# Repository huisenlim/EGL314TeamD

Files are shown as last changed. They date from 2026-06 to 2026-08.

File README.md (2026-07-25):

# EGL314 Experiental Ghost Hunting Game: POC
This repository contains the documentation of our experiential ghost hunting game utilising the **Ai-Thinker BU03-Kit** UWB modules (DW3000 + STM32F103) for live player tracking.  
This project has just passed the POC phase, and is documented as such.

## Table of Contents
1. [Project Overview](#1-Project-Overview)
2. [System Structure & Setup](#2-system-structure--setup)
* 2.1 [Basic structure](#21-basic-structure-of-system)
* 2.2 [Software & Hardware Setup](#22-software--hardware-setup)
* 2.3 [Tag configuration & Setup](#23-setup-of-tags--configuration)
3. [Game code for POC](#3-poc-game-code)  
* 3.1 [Tutorial](Tutorial.md)
4. [Running the game](#4-running-the-game)
5. [Repository Layout](#5-repository-layout)

# 1. Project Overview
This project aims to create an immersive and interactive experience through a 'ghost hunting game'.  
  
For this, the following hardware and software are used:

| Item | Qty | Remarks |
| --- | --- | --- |
| BU03-Kit UWB modules | 8 | 6 anchors and 2 tags. |
| Raspberry Pi 4 Model B | 2 | 1 rPi for running game code, and another for receiving UWB data through UART.  |
| Multiplay | - | For synchronised audio feedback |
| Physical button | 1 | Connected to game rPi so it can take in the button input. |
| Jumper wires | 2 | Soldered to the button and connected to rPi GPIO 27 |

All this is used to create a game where players use an item equipped with a rPi, button, and tag board to find and dispel ghosts through audio and visual cues.  

In order to win, the player must go dispel 3 ghosts within the 2 minute time limit by entering the vicinity of the ghost and pressing the button.   

Whenever a ghost is successfully dispelled, an additional 30 seconds is added, whereas if the button is pressed outside of the ghost's range, 5 seconds will be deducted.

# 2. System Structure & Setup

## 2.1 Basic structure of system
```mermaid
graph TD
A[BU03 Anchor 0]--UART-->B[Receiver rPi]
C[BU03 Anchor 1] --> A
D[BU03 Anchor 2] --> A
E[BU03 Anchor 3] --> A
F[BU03 Anchor 4] --> A
G[BU03 Anchor 5] --> A
B --OSC--> H[Game rPi]
H --OSC--> I[Multiplay]
```
## 2.2 Software & Hardware Setup
Before we start configuring the boards, we need to do some software setup for the Raspberry Pi by activating virtual environments and installing the required dependencies along with some hardware setup to connect the button to the Raspberry Pi.

Click [here](hardwareSoftwareSetup.md) for how.

## 2.3 Setup of tags & configuration
In this project, a single Ai-Thinker BU03-Kit module is configured as a tag, while six other modules are configured as fixed anchors placed around the game area. These are the fixed reference points used to calculate position.  

### Physical Setup
setupimg

The Raspberry Pi then reads live distance data from Anchor 00 over UART and sends it to our Game rPi which performs 2D multilateration, smooths the result with a Kalman filter, and renders live positions in a Tkinter and Matplotlib GUI.  
  
For this, each board has to be configured such that it understands its purpose and what it has to do.  

To learn more about how the BU03 modules work and how they are configured, click [here](TagSetupConfig.md)

# 3. POC game code
The programming of the game for POC includes the base game mechanic of dispelling ghosts with the tag and button, win/lose condition, synchronised SFX using Multiplay, and a [sequential tutorial](Tutorial.md).  

To view the in-depth guide on the GamePOC.py file, click [here](POCgameCode.md)

# 4. Running Tutorial and Game
To run the tutorial and game, first run uart.py on the receiver rPi using CLI inside the environment created during [software setup](https://github.com/huisenlim/EGL314TeamD/blob/main/hardwareSoftwareSetup.md#installing-virtual-environment):
```
python3 uart.py --host x.x.x.x --port 5005 --tags 1
```
Where x.x.x.x is the IP address of the game rPi.  
  
Then, simply run POCtutorial.py and GamePOC.py on the game rPi through CLI or VScode.

# 5. Repository Layout
```
.
├── README.md                  # this file
├── GamePOC.py                 # game file for POC
├── uart.py                    # for UART receiver pi
├── POCtutorial.py             # tutorial game file for POC
├── POCgameCode.md             # game file documentation
├── tutorial.md                # tutorial game file documentation
├── hardwareSoftwareSetup.md   # setup of hardware and software
├── TagSetupConfig.md          # setup and configuration of tag boards
└── ConfigFiles/               
    ├── bu03_detect.py         # UART connection confirmation
    ├── bu03_multi_config.py   # to config ID/role for each board
    ├── bu03_inspect.py        # reads back configuration
    ├── viewer_calibrate.py    # calibration for anchors
    └── check_uart.sh          # verification of UART mapping
```

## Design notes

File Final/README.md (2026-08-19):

# EGL314 Project Phantom MVP: The Final Showdown (Station 4)
An interactive and physical game of ghost hunting where player need to answer question, when they answer correctly, they are one step closer to restore the energy to kill the final ghost(bossman).

## Table of Content
1. [Project Overview](#1-Project-Overview)
2. [How The Game Works](#2-how-the-game-works)
3. [Game Setup](#3-game-setup)
*  3.1 [Equipment](#31-equipment-used)
4. [Software Setup](#4-software-setup)
*  4.1 [Audio](#41-audio-cues-setup)
*  4.2 [Visual](#42-lighting-cues-setup)
5. [Conditions For The Game](#5-conditions-for-the-game)
*  5.1 [Win Conditions](#51-win-condition)
*  5.2 [Lose Conditions](#52-lose-condition)
6. [Final Outcome](#6-final-outcome)

## 1. Project Overview
This station consists of players if they are paying attention to the trainers(host). Players have to answer 4 questions, after one correct answer the energy will be restored slowly until the last question is answered correctly, they will be able to defeat the final ghosts(bossman). The system tracks participants across defined arena zones and synchronizes stage lighting and multi-track audio to deliver a guided 4-question interactive game.

This is bossman:)
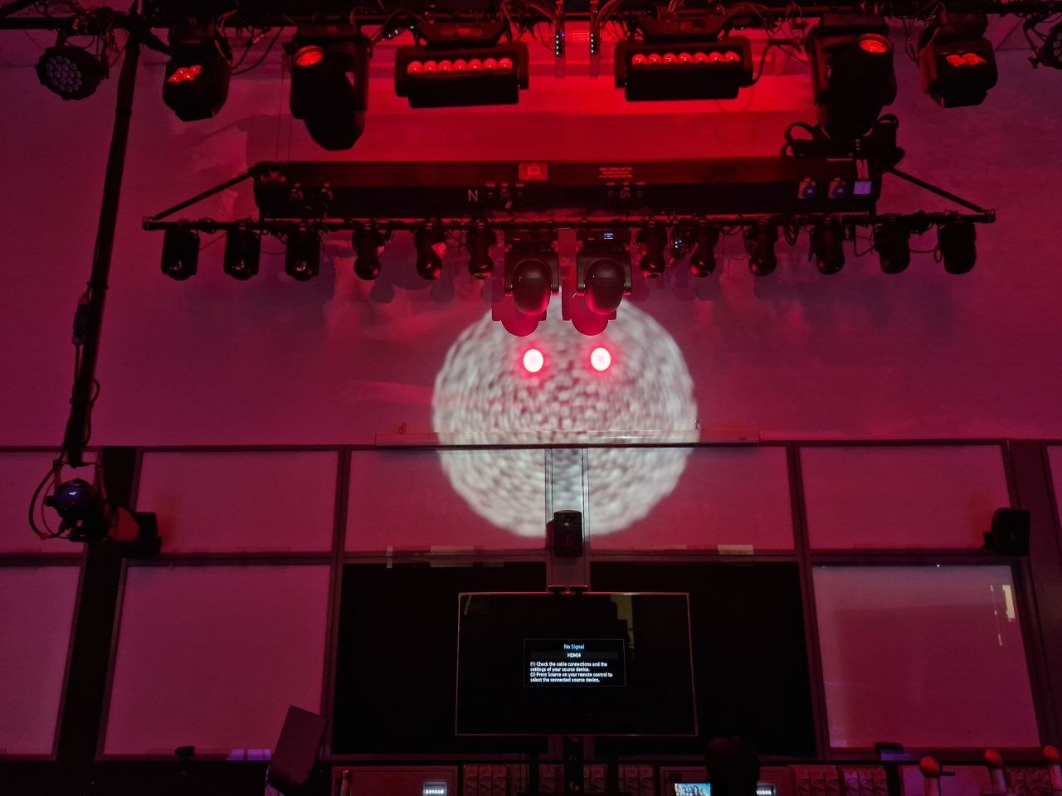
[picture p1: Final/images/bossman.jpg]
bossman


## 2. How The Game Works
The game is a synchronized spatial tracking and show automation system where trainees(players) have to answer the correct answer, trainers then will place a pillar in one of the option that the trainees(players) want and see if it is in the zone(correct option), if yes it will move on to the next question, if not players will have another try until they get correct. The Python engine processes real-time hardware positioning and coordinates stage lighting (grandMA3) and dynamic audio cues (REAPER) over Open Sound Control (OSC).

---

### **1. Zone Collision & Hit Detection**

* **Zone Radius Evaluation (`game_logic.py`)**:
Uses Euclidean distance to determine whether a smoothed tag coordinate $(px, py)$ falls within the active question's zone center $(zx, zy)$:

```python
def ptInGhost(point, ghost):
    if point is None: return False
    px, py = point; zx, zy = ghost["center"]; r = ghost["radius"] + GhostHitTol
    return ((px - zx)**2 + (py - zy)**2) <= (r * r)

```
To detect if tag is in zone.
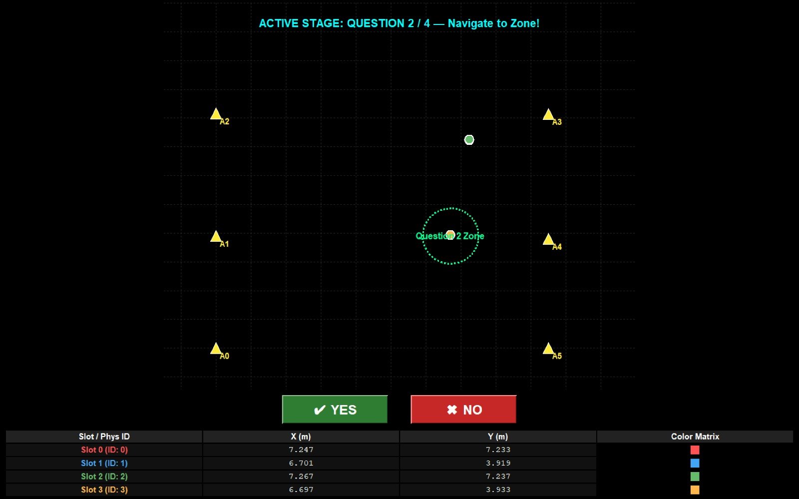
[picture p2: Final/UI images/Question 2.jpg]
tag in zone


---

### **2. Game Lifecycle & Show Automation**

* **Application Launch (`main.py`)**:
Unmutes all audio tracks in REAPER and sends grandMA3 to standby Cue 2 on Sequence 100:

```python
if hasattr(app, 'audio_controller'):
    app.audio_controller.unmute_all_tracks()

lighting.trigger_initial_startup_light()

```
When launch the code, there is a main staging light for when the trainers are first talking about how the game works.

* **Start Game Execution (`main.py`)**:
Turns off startup/tutorial lights, triggers Question 1 lights (Seq 93) with timed cues, and starts Track 6 Marker 20 intro audio:

```python
lighting.stop_startup_light()
lighting.stop_tutorial_lighting()

lighting.start_question_lighting(1)

if app and hasattr(app, 'audio_controller'):
    app.audio_controller.play_q1_intro()

```
When first run the code.
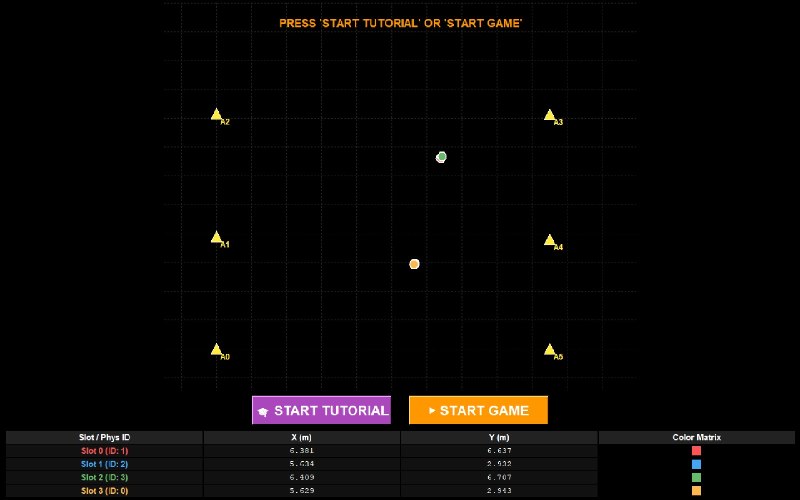
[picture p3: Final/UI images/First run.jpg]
first run


* **Timed Lighting Cues (`lighting.py`)**:
Schedules dynamic cue progression across sequences 93–96:

```python
seq_num = seq_info["question_seq"]
send_command(f"Go+ Sequence {seq_num}")

timings = QUESTION_CUE_TIMINGS.get(q_num, [])
for delay, cue in timings:
    timer = threading.Timer(delay, _trigger_cue, args=(cue, seq_num))
    active_cue_timers.append(timer)
    timer.start()

```

* **Intro-to-Ambient Audio Transition (`reaper.py`)**:
Plays the intro on Track 6 and automatically switches to Track 4 Marker 29 background audio once the intro duration finishes:

```python
self.play_marker(intro_marker_action)

self.marker_timer = threading.Timer(
    intro_duration_seconds, 
    lambda: self.play_marker(MARKER_29_TRK4)
)
self.marker_timer.start()

```
When pressed start game question 1 will be played audio and lighting will sync together when the bossman is saying the options. It will be the same until the last question is played.

This is Q1.
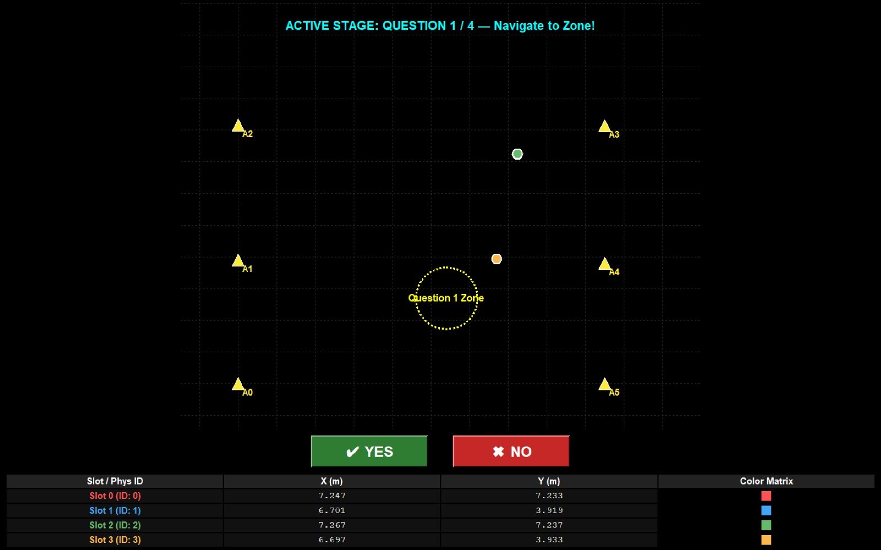
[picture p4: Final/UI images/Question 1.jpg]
Question1


This is Q2.
Question2

This is Q3.
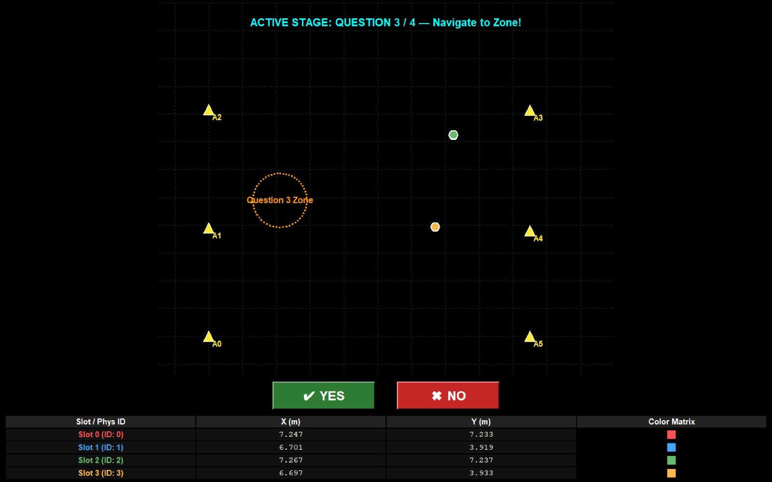
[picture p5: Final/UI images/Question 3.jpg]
Question3


This is Q4.
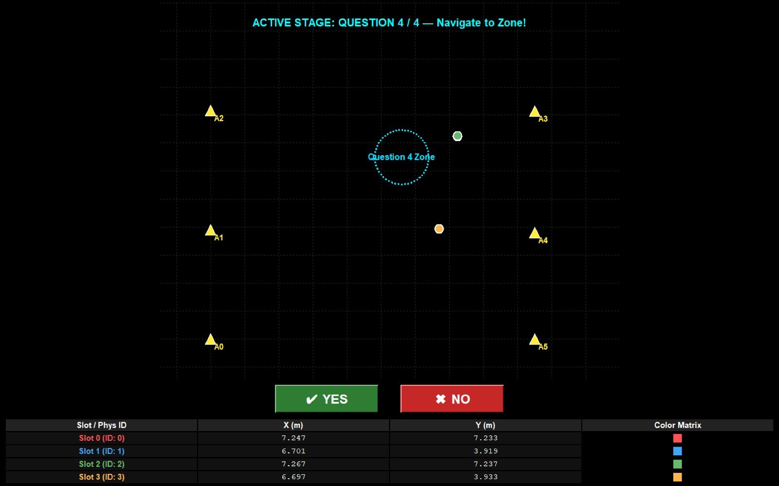
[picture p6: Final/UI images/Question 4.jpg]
Question4


---

### **3. Submissions: YES and NO Logic**

* **Standard YES (`main.py`)**:
Validates if a tag is inside the physical question zone before triggering success:

```python
for zi, ghost in enumerate(game_logic.Ghosts):
    if ghost.get("active", True) and ghost.get("question") == game_logic.CURRENT_QUESTION:
        if game_logic.ptInGhost(tag.filt_position, ghost):
            ghost["active"] = False
            hit_detected = True

if hit_detected:
    state.question_answered = True
    if app and hasattr(app, 'audio_controller') and game_logic.CURRENT_QUESTION < 4:
        app.audio_controller.play_yes_q1_to_q3()
    lighting.trigger_question_success_light(game_logic.CURRENT_QUESTION, audio_controller=audio_ctrl)

```
When tag is in the zone(correct answer), lightings will turn green and audio will play a "correct" sound when yes button is pressed.

* **NO Button & Auto-Retry Loop (`main.py` & `reaper.py`)**:
Triggers lighting Sequence 97 for 5s and plays Track 6 Marker 21 for 4s before automatically restarting the active question intro:

```python
# main.py
lighting.trigger_no_button_sequence()
if app and hasattr(app, 'audio_controller'):
    app.audio_controller.play_no_button(on_finish_callback=repeat_current_question_intro)

# reaper.py
def play_no_button(self, on_finish_callback=None):
    self._cancel_timer()
    self.play_marker(MARKER_21_TRK6)
    if on_finish_callback:
        self.marker_timer = threading.Timer(4.0, on_finish_callback)
        self.marker_timer.start()

```
When tag is not in the zone(correct answer), lightings will turn red and audio will play a "laughing" sound coming out of the bossman and audio will replay the question when no button is pressed.

This is the yes and no button.
button

---

### **4. Question 4 Finale Sequence (`lighting.py`)**

* **Multi-Stage Automated Finale**:
Fires Track 34 Marker 22 and Sequences 89 & 101, triggers Sequence 102 Cue 9 and Track 6 Marker 23 after 9 seconds, and executes grandMA3 `Go Macro 15` with Track 36 Marker 24 after 11 seconds:

```python
if q_num == 4:
    send_command("Go+ Sequence 101")
    if audio_controller:
        audio_controller.play_yes_q1_to_q3()
    threading.Timer(9.0, _q4_fade_seq102, args=(audio_controller,)).start()

def _q4_fade_seq102(audio_controller=None):
    send_command(f"Go+ Cue 9 Sequence {FINAL_DIMMER_SEQUENCE}")
    if audio_controller:
        audio_controller.play_seq102_fade_audio()
    threading.Timer(11.0, _q4_delayed_macro15_transition, args=(audio_controller,)).start()

def _q4_delayed_macro15_transition(audio_controller=None):
    send_command("Off Sequence 89")
    send_command(f"Go Macro {FINAL_MACRO}")
    if audio_controller:
        audio_controller.play_seq90_audio()

```
Once final question is correct audio will play a dialouge coming from bossman after that the bossman will fade away and victory lights will be cued.

---

### **5. End Game Cleanup (`main.py` & `lighting.py`)**

* **Safe System Teardown**:
Stops all active audio transport in REAPER and sends grandMA3 to Cue 9 on Sequence 102:

```python
# main.py
if app and hasattr(app, 'audio_controller'):
    app.audio_controller.stop_all_audio()

lighting.end_game_lighting_cleanup()

# lighting.py
def end_game_lighting_cleanup():
    cancel_active_cue_timers()
    send_command(f"Go+ Cue 9 Sequence {FINAL_DIMMER_SEQUENCE}")

```
Once end game button is pressed, it will stop all cues both lighting and audio.

This is the end game button.
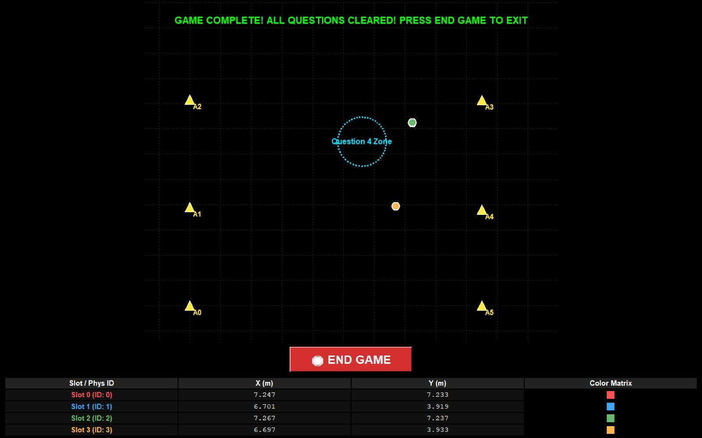
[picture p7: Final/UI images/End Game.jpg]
End Game


---

## 3. Game Setup
### 3.1 Equipment used
| Item | Qty | Remarks |
| --- | --- | --- |
| BU03-Kit UWB modules | 10 | 6 anchors and 4 tags. |
| Laptop | 1 | for running game code, and another for receiving UWB data through UART.  |

## 4. Software Setup
For software both audio and lighting need to sync with each other to obtain the perfect game.
### 4.1 Audio Cues Setup
#### 🛠️ 1. REAPER OSC Configuration

To allow Python to trigger audio markers over UDP:

1. Open REAPER.
2. Go to **Options** > **Preferences** (`Ctrl+P` / `Cmd+,`).
3. Under **Control/OSC/web**, click **Add**.
4. Configure:
   - **Control surface mode:** `OSC (Open Sound Control)`
   - **Pattern config:** `Default`
   - **Mode:** `Receive on UDP port`
   - **Listen port:** `8000`
5. Click **OK** and **Apply**.

---

#### 📌 2. REAPER Track & Marker Mapping

Question triggers route through **Track 3**, while game events route through **Tracks 33–36**:

| Track | Event / Scenario | Marker ID | Action |
| :--- | :--- | :---: | :--- |
| **Track 3** | Question 1 Audio | **20** | `Q1 Start / Cue` |
| **Track 3** | Question 2 Audio | **25** | `Q2 Start / Cue` |
| **Track 3** | Question 3 Audio | **26** | `Q3 Start / Cue` |
| **Track 3** | Question 4 Audio | **27** | `Q4 Start / Cue` |
| **Track 33** | Miss the Ghost | **21** | `Miss Sound Effect` |
| **Track 34** | Hit the Ghost | **22** | `Hit Sound Effect` |
| **Track 35** | Ghost Lose / Defeated | **23** | `Ghost Defeat Music` |
| **Track 36** | Victory Song | **24** | `Victory Fanfare` |

---

#### 💡 3. Audio & Lighting Synchronization Matrix

When an event triggers in Python, it dispatches OSC messages to both REAPER (`127.0.0.1:8000`) and grandMA3 (`192.168.254.252:8080`):

| Game Event | REAPER Track | REAPER Marker | grandMA3 Sequence |
| :--- | :---: | :---: | :--- |
| **Question 1** | Track 3 | Marker 20 | Sequence `93` |
| **Question 2** | Track 3 | Marker 25 | Sequence `94` |
| **Question 3** | Track 3 | Marker 26 | Sequence `95` |
| **Question 4** | Track 3 | Marker 27 | Sequence `96` |
| **Miss Ghost** | Track 33 | Marker 21 | Sequence `103` |
| **Hit Ghost** | Track 34 | Marker 22 | Sequence `104` |
| **Ghost Defeated** | Track 35 | Marker 23 | Sequence `105` |
| **Victory Song** | Track 36 | Marker 24 | Sequence `106` |

---
### 4.2 Lighting Cues Setup
The lighting module is responsible for sending Open Sound Control (OSC) commands directly to a grandMA3 console. It manages the visual atmosphere of the Interactive Question Arena by triggering specific light sequences, timed cues, and macros dynamically based on the active game state.

```python
# ───────── GMA3 NETWORK CONFIGURATION ─────────
GMA3_IP = "192.168.254.252"   # Replace with your grandMA3 console IP
GMA3_PORT = 8080             # Default grandMA3 inbound OSC port
GMA3_ADDR = "/gma3/cmd"
# ─────────────────────────────────────────────
```

```python
try:
    client = udp_client.SimpleUDPClient(GMA3_IP, GMA3_PORT)
    print(f"[LIGHTING] Connected to grandMA3 at {GMA3_IP}:{GMA3_PORT}")
except Exception as e:
    client = None
    print(f"[LIGHTING ERROR] Failed to initialize OSC client: {e}")
```

To execute these actions on the console, a helper function converts string commands into raw OSC messages:
```python
def send_command(cmd_string: str):
    """Sends a raw command string to the grandMA3 command line."""
    if client:
        try:
            client.send_message(GMA3_ADDR, cmd_string)
        except Exception as err:
            print(f"[LIGHTING ERROR] Network send failed: {err}")
```
### 4.3 Lighting Setup Checklist
Use this checklist to verify that all Open Sound Control (OSC) commands from the Python game server are successfully reaching the grandMA3 console and triggering the correct sequences.

## 1. Network & Initialization
- [ ] **Network Connection:** Verify the grandMA3 console is set to IP `192.168.254.252` and listening for OSC on UDP port `8080`.
- [ ] **Application Launch:** Run `python main.py`. 
  - *Expected Console Action:* Triggers `Go+ Cue 2 Sequence 100`.
  - *Visual Check:* Baseline environmental startup lighting is active.

## 2. UI & Pre-Game States
- [ ] **Tutorial Mode:** Click **START TUTORIAL**.
  - *Expected Console Action:* Triggers `Go+ Sequence 91`.
- [ ] **Game Start Initialization:** Click **START GAME**.
  - *Expected Console Action:* Sends `Off Sequence 100` and `Off Sequence 91`.
  - *Expected Console Action:* Immediately triggers `Go+ Sequence 93` (Question 1 Intro).

## 3. Question Intros & Timed Cues
- [ ] **Staggered Cues (Stage 1):** While Question 1 is active, do not press any buttons for 20 seconds.
  - *Expected Console Action:* Automatically triggers Cues 1, 2, 3, and 4 on Sequence `93` at the 6s, 10s, 14s, and 18s marks.

## 4. Game Action Responses
- [ ] **Lose Condition (NO Button):** Click **NO**.
  - *Expected Console Action:* Triggers `Go+ Sequence 97`.
  - *Expected Console Action:* Wait exactly 5 seconds; system should automatically send `Off Sequence 97`.
- [ ] **Win Condition (YES Button):** Physically enter the Question 1 zone and click **YES**.
  - *Expected Console Action:* Turns `Off Sequence 93`.
  - *Expected Console Action:* Triggers Success `Go+ Sequence 86`.
- [ ] **Stage Progression (CONTINUE Button):** Click **CONTINUE**.
  - *Expected Console Action:* Turns `Off Sequence 86`.
  - *Expected Console Action:* Triggers the next stage intro `Go+ Sequence 94`.

## 5. Final Boss Sequence (Question 4)
- [ ] **Boss Win Trigger:** Reach Question 4, enter the zone, and click **YES**.
  - *Expected Console Action:* Turns `Off Sequence 96`.
  - *Expected Console Action:* Triggers `Go+ Sequence 89` and `Go+ Sequence 101` simultaneously.
- [ ] **Boss Fade (9s Delay):** Wait 9 seconds after the boss win.
  - *Expected Console Action:* System automatically triggers `Go+ Cue 9 Sequence 102`.
- [ ] **Boss Conclusion (11s Delay):** Wait another 11 seconds (20s total).
  - *Expected Console Action:* Turns `Off Sequence 89`.
  - *Expected Console Action:* Executes `Go Macro 15`.

## 6. System Shutdown
- [ ] **End Game:** Click the **END GAME** button.
  - *Expected Console Action:* Pending timers are cancelled.
  - *Expected Console Action:* Triggers `Go+ Cue 9 Sequence 102` to bring the arena to its final resting state.

### 4.4 grandMA3 OSC Configuration Guide
To allow the Python game server to communicate with the grandMA3 console, you must configure the console to receive incoming Open Sound Control (OSC) network commands. 

### 1. Network Session Verification
Before configuring OSC, ensure your console or onPC software is active within a network session.
*   Navigate to the **Network** menu.
*   Verify that your station is actively in a session (indicated by the green highlight in the station list).

OSC LIGHT NETWORK SESSION

### 2. OSC In & Out Configuration
The core communication settings are established in the OSC Input/Output menu.

Navigate to the **In & Out** menu and select the **OSC** tab on the left sidebar.

Configure the global OSC settings at the top of the screen:
*   **Interface:** Select the network interface that matches your local network IP (e.g., `Wi-Fi (192.168.254.252)`).
*   **Enable Output:** Ensure this button is toggled ON (highlighted in yellow).
*   **Enable Input:** Ensure this button is toggled ON (highlighted in yellow) to allow the console to listen for commands.

### 3. OSC Data Setup
Create a new OSC Data row (e.g., `OSCData 1`) in the main window and apply the following specific configuration parameters:

*   **Destination IP:** `192.168.254.252`
*   **Mode:** `UDP`
*   **Port:** `8080` (This must match the `GMA3_PORT` defined in your Python script)
*   **Prefix:** `gma3` (This acts as the root address block for incoming commands)

Ensure the following command toggles are enabled for this data row:
*   **Receive:** `Yes`
*   **Send:** `Yes`
*   **Receive Command:** `Yes` (Crucial for allowing remote execution of macros and sequences)
*   **Send Command:** `Yes`

OSC LIGHT

## 5. Conditions For The Game
When playing a trivia question game, there is always a correct and wrong answer.

### 5.1 Win Condition
To win the game, players must answer all 4 question correctly in order to defeat the final ghost(bossman).
#### Audio Part

#### Lighting Part
Sequence & Cue Mappings
Specific grandMA3 sequences are mapped to global game events:
*   **Startup State:** Sequence `100` (automatically triggers Cue 2 upon application launch).
*   **Tutorial Mode:** Sequence `91`.
*   **Incorrect Action (NO Button):** Sequence `97` (plays for exactly 5 seconds before a background thread automatically turns it off).
*   **End Game / Final Dimmer:** Sequence `102` (specifically Cue 9).
The game dynamically triggers specific grandMA3 sequences and timed cues based on player actions and UI events.

System Startup
When the application first launches, it triggers a baseline environmental lighting state.
```python
def trigger_initial_startup_light():
    """Runs Cue 2 on Sequence 100 upon application launch."""
    print("[LIGHTING] App Launched: Triggering Cue 2 on Sequence 100...")
    send_command(f"Go+ Cue 2 Sequence {STARTUP_SEQUENCE}")
```

#### Question & Success Sequences
Each of the 4 progressive game questions utilizes a dedicated introductory sequence and a corresponding success sequence upon clearance:
*   **Question 1:** Intro Sequence `93` ➔ Success Sequence `86`.
*   **Question 2:** Intro Sequence `94` ➔ Success Sequence `87`.
*   **Question 3:** Intro Sequence `95` ➔ Success Sequence `88`.
*   **Question 4 (Boss Stage):** Intro Sequence `96` ➔ Success Sequence `89`.

When a player physically enters an active Question Zone and successfully clicks YES, the system turns off the introductory sequence and fires a success sequence. 
```python
def trigger_question_success_light(q_num: int, audio_controller=None):
    """
    Cancels pending intro cues, turns OFF question sequence (93-96), 
    and runs corresponding success sequence (86-89).
    """
    cancel_active_cue_timers()  # Stop any intro cues from firing late
    
    seq_info = QUESTION_SEQUENCES.get(q_num)
    if seq_info:
        send_command(f"Off Sequence {seq_info['question_seq']}")
        send_command(f"Go+ Sequence {seq_info['success_seq']}")
```

### 5.2 Lose Condition
Players will only lose when they get the answer wrong but they can try again until they get it right.
#### Audio Part

#### Lighting Part
## ❌ Lose Condition (Incorrect Action)

A lose or incorrect condition occurs when a player clicks the **NO** button on the game dashboard. This is used to indicate an incorrect answer or action, temporarily halting the current hunt.

When the **NO** button is clicked, the system triggers `trigger_no_button_sequence()`:
*   **Trigger:** The system sends a `Go+ Sequence 97` command to the grandMA3 console.
*   **Duration:** This sequence plays a specific error lighting state for exactly 5 seconds.
*   **Reset:** A background thread automatically sends an `Off Sequence 97` command after the 5 seconds have elapsed. Following this, the audio and lighting intros for the current question are automatically repeated so the player can try again.

```python
def trigger_no_button_sequence():
    """Plays Sequence 97 for 5 seconds when NO is pressed, then turns it off."""
    print("[LIGHTING] NO Button Pressed: Triggering Sequence 97 for 5 seconds...")
    send_command(f"Go+ Sequence {NO_BUTTON_SEQUENCE}")
    
    # Schedule automatic OFF after 5 seconds
    threading.Timer(5.0, _stop_no_button_sequence).start()

def _stop_no_button_sequence():
    """Helper timer callback to turn OFF Sequence 97."""
    print("[LIGHTING] 5s elapsed: Turning OFF Sequence 97...")
    send_command(f"Off Sequence {NO_BUTTON_SEQUENCE}")
```

### 5.3 Output of game

These images show the output of the lighting effect of the game
Question 1
Q1
Question 2
Q2
Question 3
Q3
Question 4

Q4

## 6. Final Outcome
After defeating the final ghost(bossman), victory is served and trainees would be able to obtain their license to become a trainer.
#### Audio Part

#### Lighting Part
## Core Logic & Functions

## `start_question_lighting(q_num)`
Clears any active lighting timers to prevent cue overlap, activates the target question's intro sequence, and schedules the staggered timed cues required for that specific question.

## `trigger_question_success_light(q_num, audio_controller)`
Executed when players successfully conquer a containment field. It cancels any pending intro cues, turns off the active question sequence, and immediately activates the corresponding success sequence. 

### The Boss Transition Logic (Question 4)
When Question 4 is cleared, the system executes a complex, threaded chain of audio-visual events to conclude the hunt:
1.  **Phase 1:** Sequence `101` fires, accompanied by Track 34 Marker 22 audio playback.
2.  **Phase 2 (9s Delay):** The system triggers Cue 9 on Sequence `102` (Final Dimmer) while simultaneously triggering the track fade-out audio marker.
3.  **Phase 3 (11s Delay):** Once the audio fade finishes, Sequence `89` is turned off, Macro `15` is executed, and the final concluding audio marker plays.

### 👑 Final Boss Win (Question 4)
Defeating the final ghost (Question 4) triggers a specialized, multi-phase grandMA3 lighting transition to signify the end of the game:
1.  **Initial Clear:** Turns OFF Sequence `96`, triggers Success Sequence `89`, and simultaneously fires Sequence `101`.
2.  **9-Second Delay:** The system waits 9 seconds before automatically triggering Cue 9 on Sequence `102` (Final Dimmer fade).
3.  **11-Second Delay:** After 11 more seconds, the system turns OFF Sequence `89` and executes Macro `15` to conclude the visual experience.

For the final boss stage (Question 4), a special delayed lighting and audio transition sequence is triggered using threading.
```python
    # --- Special Transition Logic for Question 4 / Sequence 89 ---
    if q_num == 4:
        print("[LIGHTING] Q4 Cleared: Seq 89 active! Playing Track 34 Marker 22...")
        send_command("Go+ Sequence 101")
        
        # Step 1: Play Track 34 Marker 22 when Sequence 89 starts
        if audio_controller:
            audio_controller.play_yes_q1_to_q3()

        # Step 2: Hold for 9s before triggering Cue 9 on Sequence 102
        threading.Timer(9.0, _q4_fade_seq102, args=(audio_controller,)).start()
```
### Cleanup Utilities
*   **`cancel_active_cue_timers()`:** A safety utility that iterates through `active_cue_timers` and stops them, ensuring overlapping button presses don't cause late-firing cues.
*   **`end_game_lighting_cleanup()`:** Safely shuts down pending timers and triggers Cue 9 on Sequence `102` to dim the physical arena when the game session fully terminates.

## 📁 Repository Layout

The project is divided into the main host server scripts (which run the game engine, UI, and OSC integrations) and a lightweight hardware script intended for the Raspberry Pi.

```text
📦 EGL314TeamD
├── 📜 README.md             # Main project documentation
├── 🖥️ Host Server (Laptop/PC)
│   ├── 📜 main.py           # Central execution script; initializes UI and servers
│   ├── 📜 display.py        # Tkinter game dashboard and real-time visualization
│   ├── 📜 game_logic.py     # Defines anchor coordinates, play bounds, and zone logic
│   ├── 📜 game_state.py     # Thread-safe data classes managing player positions
│   ├── 📜 network.py        # OSC handler that throttles and processes UWB packets
│   ├── 📜 trilateration.py  # 2D positioning math and Kalman filter for smoothing
│   ├── 📜 tutorial_ui.py    # Dedicated UI module for player onboarding
│   ├── 📜 lighting.py       # grandMA3 integration for dynamic lighting cues
│   └── 📜 reaper.py         # REAPER DAW integration for automated audio mixing
└── 🍓 Raspberry Pi (Hardware)
    └── 📜 pi_transmitter.py # Reads UART sensor data and GPIO button presses via OSC
```

### 8. System Architecture
```mermaid
graph TD
    %% 1. Top Level Hardware & Sensor Node
    A[AI Thinker UWB Kit] -->|UART| B[Laptop -> game.py]
    
    %% 2. Core Game Logic Node
    B -->|OSC| C[Laptop -> game.py]
    
    %% 3. Subsystem Split
    C -->|OSC| D[REAPER]
    C -->|OSC| E[GrandMA3]
    
    %% 4. Lighting Subsystem
    E -->|Wireless DMX| F[Lighting Fixtures]
    
    %% 5. Audio Subsystem Pipeline
    D -->|Dry digital audio| G[L-ISA Processor]
    H[L-ISA Controller] -->|Control data| G
    G -->|Rendered audio via Dante| I[Yamaha QL1]
    I -->|Dante| J[Yamaha Amplifier]
    J -->|Amplified analog audio| K[Yamaha Speakers]

    %% Styling & Customizations
    style A fill:#1f2937,stroke:#6b7280,stroke-width:1px,color:#fff
    style B fill:#1f2937,stroke:#6b7280,stroke-width:1px,color:#fff
    style C fill:#1f2937,stroke:#6b7280,stroke-width:1px,color:#fff
    style D fill:#1f2937,stroke:#6b7280,stroke-width:1px,color:#fff
    style E fill:#1f2937,stroke:#6b7280,stroke-width:1px,color:#fff
    style F fill:#1f2937,stroke:#6b7280,stroke-width:1px,color:#fff
    style G fill:#1f2937,stroke:#6b7280,stroke-width:1px,color:#fff
    style H fill:#1f2937,stroke:#6b7280,stroke-width:1px,color:#fff
    style I fill:#1f2937,stroke:#6b7280,stroke-width:1px,color:#fff
    style J fill:#1f2937,stroke:#6b7280,stroke-width:1px,color:#fff
    style K fill:#1f2937,stroke:#6b7280,stroke-width:1px,color:#fff

    linkStyle default stroke:#9ca3af,stroke-width:1px,color:#9ca3af
```

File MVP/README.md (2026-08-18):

# EGL314 Project Phantom MVP: The Final Showdown (Station 4)
An interactive and physical game of ghost hunting where player position determines real-time tracking with audio and visual cues to elimate the ghosts.

## Table of contents
1. [Project Overview](#1-Project-Overview)
2. [How The Game Works](#2-how-the-game-works)
3. [Game Setup](#3-game-setup)
*  3.1 [Real-Time Tracking Setup](#31-tag-and-anchor-setup)
*  3.2 [Button Setup](#32-button-setup)
*  3.3 [Gun Setup](#33-gun-setup)
4. [Software Setup](#4-software-setup)
*  4.1 [Audio](#41-audio-cues-setup)
*  4.2 [Visual](#42-lighting-cues-setup)
5. [Conditions For The Game](#5-conditions-for-the-game)
*  5.1 [Win Conditions](#51-win-condition)
*  5.2 [Lose Conditions](#52-lose-condition)
6. [Final Outcome](#6-final-outcome)
*  6.1 [Overview Setup](#61-setup-overview)
*  6.2 [Session Flow](#62-session-flow-start-to-finish)
*  6.3 [Outcome](#63-final-outcomes)
*  6.4 [Checklists](#64-setup-checklist)
*  6.5 [Gameplay In Action](#65-gameplay-in-action)
*  6.6 [Demo](#66-demo-video)

## 1. Project Overview
An interactive, physical ghost-hunting experience where real-world player position drives a live game. Players carry UWB (ultra-wideband) location tags; the system trilaterates their position in an arena, checks it against "ghost" containment zones, and reacts in real time with a live arena visualization, dynamic stage lighting (grandMA3), and spatial audio (REAPER + L-ISA). Dispelling a ghost means physically walking into its zone and pressing a handheld button at the right moment.

## 2. How The Game Works
Players will be in an arena space which is in 536 classroom to clear ghosts("zones") across progressive waves before the countdown timer stops.

#### Tutorial Phase
* The application launches into a standby state.
* Players complete interactive tutorial prompts to learn position-tracking and pin/button mechanics.

#### Wave Progression & Area Clearing
* Completing the tutorial initiates the master countdown timer and unmutes the venue audio system.
* Target zones ("Ghosts") render on the arena map corresponding to the active Wave (Waves 1 through 3).
* There are 3 ghosts each in wave 1 and 2 and in the final wave there is one final boss to hunt.
* Players must physically move their assigned tracking tags into active target circles to clear them.
* Listen to the audio cues and and see the visual cues which is the lightings to know where the ghosts are.
* Clearing all target zones in the current wave automatically advances the arena to the next Wave stage.

```python
def setup_wave_ghosts():
    names = ["Bob", "Stewart", "Tim", "Kevin", "Carl", "Dave", "Jerry"]
    colors = ["#ffff00", "#00ff95", "#ff9900", "#00e1ff", "#f088f0", "#ff007f", "#fc9090"]
    ZONE_RADIUS = 0.80 
    
    ghosts_list = [
        {"center": (2.5, 6.0), "radius": ZONE_RADIUS, "min_radius": 0.10, "color": colors[0], "label": names[0], "active": True, "wave": 1},
        {"center": (7.0, 6.0), "radius": ZONE_RADIUS, "min_radius": 0.10, "color": colors[1], "label": names[1], "active": True, "wave": 1},
        {"center": (4.75, 3.5), "radius": ZONE_RADIUS, "min_radius": 0.10, "color": colors[2], "label": names[2], "active": True, "wave": 1},
        {"center": (2.5, 2.5), "radius": ZONE_RADIUS, "min_radius": 0.10, "color": colors[3], "label": names[3], "active": True, "wave": 2},
        {"center": (7.0, 2.5), "radius": ZONE_RADIUS, "min_radius": 0.10, "color": colors[4], "label": names[4], "active": True, "wave": 2},
        {"center": (4.75, 6.0), "radius": ZONE_RADIUS, "min_radius": 0.10, "color": colors[5], "label": names[5], "active": True, "wave": 2},
    ]
    
    # Generate random static coordinates for Wave 3 (Jerry)
    while True:
        rand_x = random.uniform(1.0, 8.5)
        rand_y = random.uniform(1.0, 7.0)
        too_close = False
        for existing in ghosts_list:
            ex, ey = existing["center"]
            if (rand_x - ex)**2 + (rand_y - ey)**2 < (1.80 ** 2):
                too_close = True
                break
        if not too_close:
            break

    ghosts_list.append({
        "center": (rand_x, rand_y),
        "radius": ZONE_RADIUS, 
        "min_radius": 0.10, 
        "color": colors[6], 
        "label": names[6], 
        "active": True, 
        "wave": 3
    })
    return ghosts_list

Ghosts = setup_wave_ghosts()
```

#### Win / Lose Conditions
* **Victory:** All target zones across all waves are cleared before the countdown hits `0.0s`.
* **Defeat:** The timer reaches `0.0s` while active targets remain uncleared.
---
This is Wave 1.
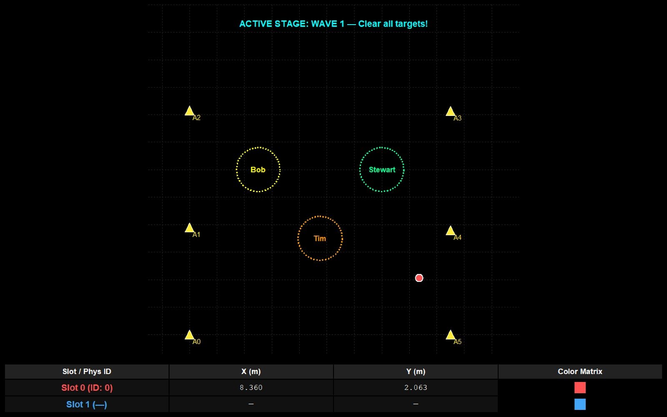
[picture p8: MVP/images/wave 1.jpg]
Wave 1


This is Wave 2.
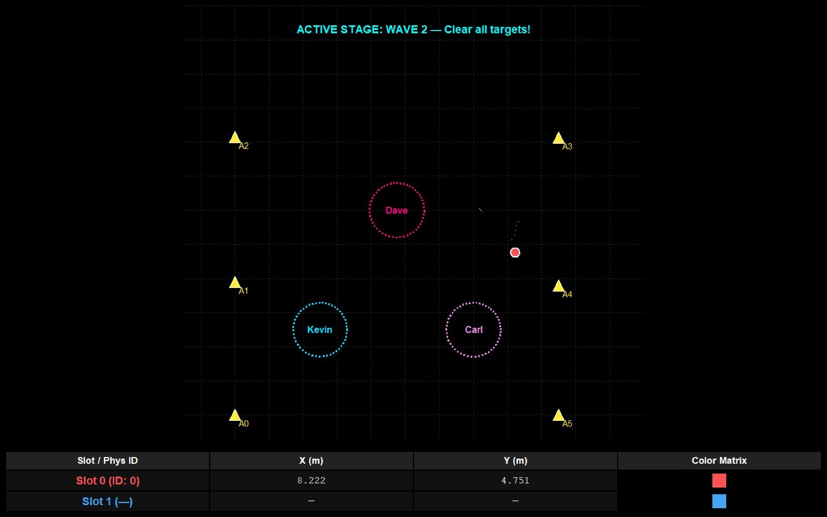
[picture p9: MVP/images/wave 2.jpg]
Wave 2


This is Wave 3 but coordinates will change everytime the code runs.
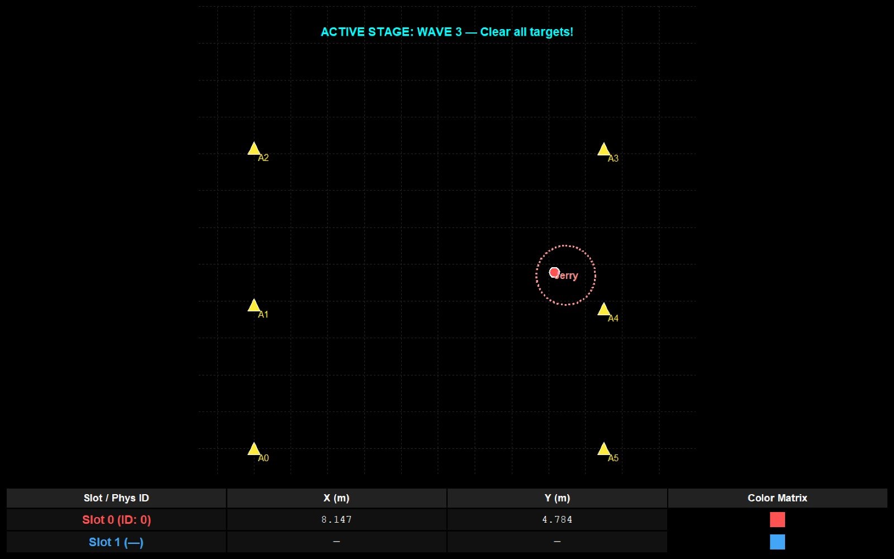
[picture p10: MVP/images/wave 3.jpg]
Wave 3


---
Next we will show you how the game is setup together with the software.

## 3. Game Setup
When setting up the game, we need some physical components to make the game work like tags and anchor, button, and lastly creating of the gun so it makes the game looks real and interesting.

### 3.1 Tag and Anchor Setup
The Ghost Game uses six fixed UWB anchors positioned around the play area to create a tracking zone. The anchors communicate with the UWB tag carried by the player, allowing the system to measure distances and calculate the player's real-time position within the game area.

The anchors act as fixed reference points, while the tag moves with the player. By using the distance measurements between the tag and multiple anchors, the system can determine the player's location and track their movement in relation to the virtual ghosts.

UWB Anchor Configuration

This is 1 of 6 anchors positioned around the play area for a tracking zone.
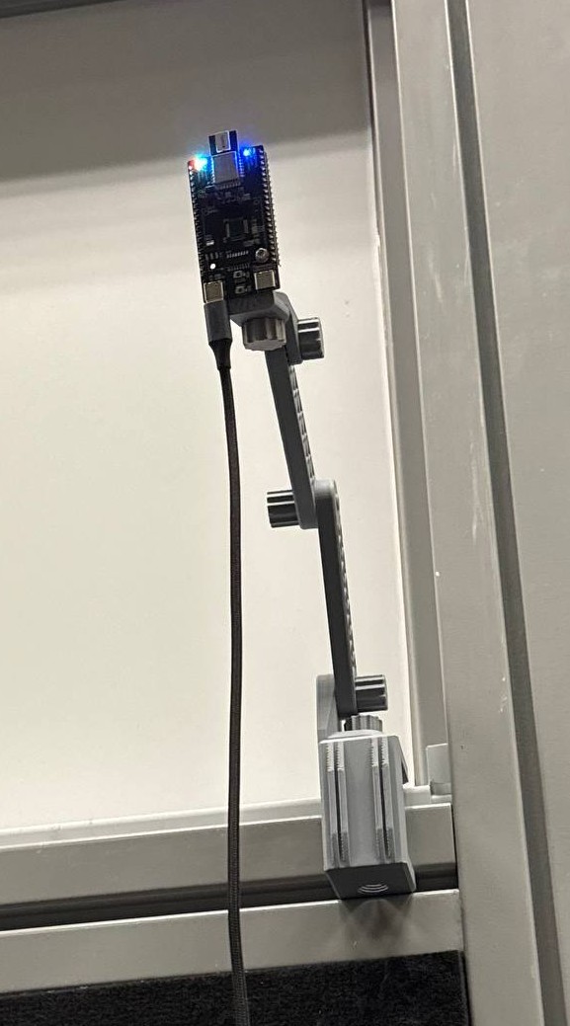
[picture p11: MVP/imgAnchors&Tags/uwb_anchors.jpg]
UWB Anchor Configuration


This is the top view of the tag used during MVP

The UWB tag was positioned at a higher level on the player to reduce the possibility of signal obstruction caused by the human body. Since the human body can interfere with or block the direct signal path between the UWB tag and the surrounding anchors, placing the tag higher provides a clearer line of sight to the anchors.

This helps improve the reliability and stability of the distance measurements as the player moves around the tracking area. The higher placement also reduces the chance of the tag being obstructed by the player's body, helping the UWB system maintain more consistent tracking performance.

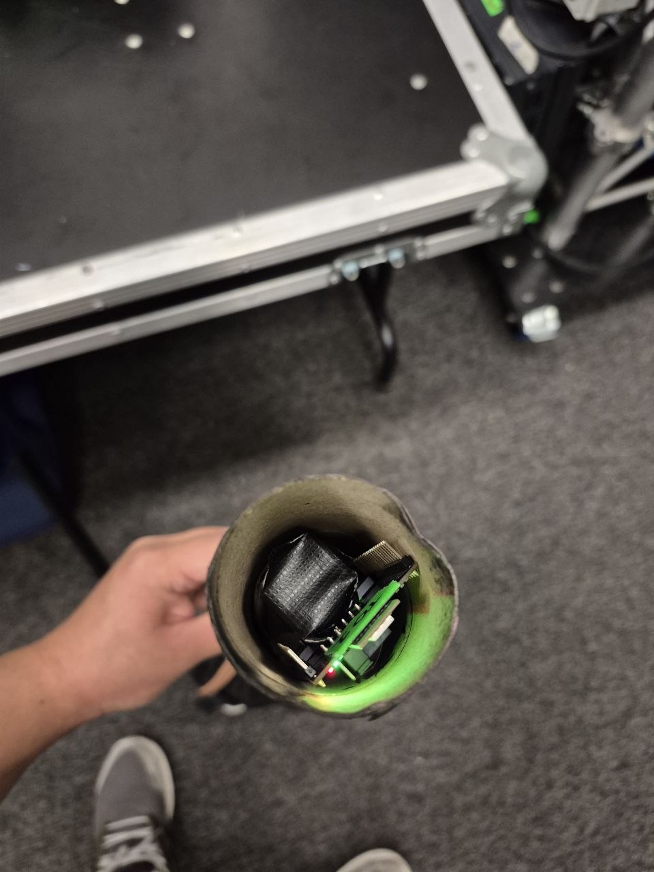
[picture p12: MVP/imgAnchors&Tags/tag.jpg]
UWB Anchor Configuration


The UWB tag was attached to the end of a rod, which was then placed inside a haversack worn by the player. This setup positioned the tag higher on the player's body, helping to reduce signal obstruction caused by the human body. By elevating the tag, a clearer line of sight was maintained between the tag and the surrounding UWB anchors, improving the reliability and consistency of the tracking system during gameplay.

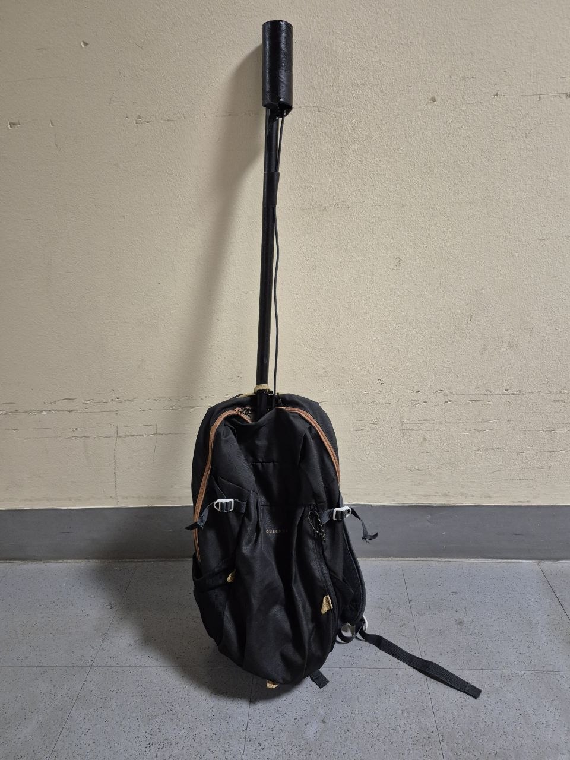
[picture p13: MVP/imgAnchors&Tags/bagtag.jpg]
UWB Anchor Configuration


These are the some 3d print used for the mount for the anchors.

These are the arms
[Click this link](3dPrintedFiles/longarms.3mf) to view the 3D print used for the UWB anchor.

These are the screws
[Click this link](3dPrintedFiles/screws.3mf) to view the 3D print used for the UWB anchor.

These is the clamp that holds the arms and screws together
[Click this link](3dPrintedFiles/clamp.3mf) to view the 3D print used for the UWB anchor.

This is the holder that i edited on UbuntuStudios so i can drill 2 small 2.5mm imperial screws through for a strengthened and stabalised anchor
 to view the 3D print used for the UWB anchor.

```python

ANCHORS = {
    0: (0.0, 0.0),
    1: (0.0, 3.9),
    2: (0.0, 8.16),
    3: (9.5, 8.14),
    4: (9.5, 3.8),
    5: (9.5, 0.0),
}

VIEW_BOUNDS = (-1.50, 12.0, -1.50, 12.0)
GhostHitTol = 0.25  
```

### 3.2 Button Setup
The dispel trigger is a single momentary push button wired to the Raspberry Pi's GPIO, read continuously in the background and forwarded to the game laptop as an event.

#### Wiring

| Pi Pin | Connection |
|---|---|
| GPIO 18 (BCM) | Button signal leg |
| GND | Button other leg |

The button is configured with an **internal pull-up**, so the pin reads HIGH when idle and LOW when pressed — `gpiozero` handles the inversion automatically.

```python
from gpiozero import Button

BUTTON_PIN = 18  # GPIO 18

button = Button(BUTTON_PIN, pull_up=True, bounce_time=0.2)
```

- `pull_up=True` — enables the internal pull-up resistor so no external resistor is needed
- `bounce_time=0.2` — 200ms software debounce, prevents a single physical press from registering as multiple rapid presses

#### Event handling

`gpiozero` exposes clean press/release callbacks, which are bound to a small helper that sends an OSC message to the game laptop:

```python
def send_button_event(is_pressed: bool):
    print(f"[PI] Button {'PRESSED' if is_pressed else 'RELEASED'} -> Sending to Laptop")
    client.send_message("/button", 1 if is_pressed else 0)

button.when_pressed  = lambda: send_button_event(True)
button.when_released = lambda: send_button_event(False)
```

Every press/release is sent as an OSC message to `/button` with a payload of `1` (pressed) or `0` (released). On the laptop side, `main.py` listens for this address and only acts on the **press** edge (not release) to avoid double-triggering:

```python
disp.map("/button", handle_remote_button)
```

For development without a Pi, the laptop also binds the **spacebar** to the same event handler, so the whole game can be tested without any hardware attached.

These photos shows the placement of the Raspberry Pi and button
photo_6280607123523702845_y
photo_6282823279403799343_y

---

### 3.3 Gun Setup

The "gun" is the handheld unit each player carries — it combines the **position tag** (UWB, reporting distance to anchors over UART) and the **dispel button** into one Raspberry Pi–driven transmitter. Its only job is to read hardware and forward everything to the game laptop over the network via OSC; it does no game logic itself. 

This is the link to all the components to 3D Print for the gun [3D Print Gun](./MVP/3dPrintedFiles/3D%20Print%20Gun/)

#### Components

- Raspberry Pi (or Pi Zero, depending on form factor)
- UWB tag module wired to the Pi's UART (`/dev/ttyS0` or `/dev/ttyUSB0`)
- Momentary push button on GPIO 18 (see [Button Setup](#1-button-setup))
- Wi-Fi connection to the same network as the game laptop

#### Configuration

Before deploying a gun, set these constants at the top of `pi_transmitter.py`:

```python
LAPTOP_IP = "192.168.1.XXX"  # Game laptop's local IP address
PORT = 5005                  # Must match --port used when launching main.py

SERIAL_PORT = "/dev/ttyS0"   # Or /dev/ttyUSB0 for a USB-to-UART adapter
BAUD_RATE = 115200
BUTTON_PIN = 18
```

> ⚠️ `LAPTOP_IP` is a placeholder — it must be updated to the actual laptop IP before each session, since it can change between networks/venues.

#### Runtime behavior

On startup, the gun opens a serial connection to the UWB tag and an OSC client pointed at the laptop:

```python
client = udp_client.SimpleUDPClient(LAPTOP_IP, PORT)
ser = serial.Serial(SERIAL_PORT, BAUD_RATE, timeout=0.1)
ser.flushInput()
```

It then loops continuously:

1. **Reads a line from UART** whenever data is available — the tag reports distances as a CSV string: `tag_id, d0, d1, d2, d3, d4, d5`
2. **Validates the packet** — needs at least 7 comma-separated values (1 tag ID + 6 anchor distances) to match what `network.py` expects on the laptop side
3. **Converts and forwards** the values as a `/distances` OSC message; malformed lines are silently skipped
4. **Button presses/releases** fire independently and asynchronously via the `gpiozero` callbacks described above — they aren't tied to the UART polling loop, so the gun stays responsive even if UART data is delayed

```python
if len(parts) >= 7:
    try:
        osc_payload = [float(val) for val in parts]
        client.send_message("/distances", osc_payload)
    except ValueError:
        pass  # Skip corrupted lines
```

A short `time.sleep(0.01)` keeps the polling loop from pegging the CPU while still comfortably outpacing the 20Hz throttle applied on the receiving end (`network.py`).

#### Multiple guns

Each gun just needs a unique `tag_id` embedded in its UART payload — the laptop auto-assigns each new physical tag ID to the next free UI "slot" the first time it's seen, so no per-gun code changes are required beyond flashing/wiring the tag itself.

---

## 4. Software Setup
Software setup is needed for audio cues and visual cues so that players will be able to hunt the ghosts by lightings and listening to the sound.

### 4.1 Audio Cues Setup

#### 🛠️ 1. REAPER OSC Configuration

To allow Python to trigger audio markers over UDP:

1. Open REAPER.
2. Go to **Options** > **Preferences** (`Ctrl+P` / `Cmd+,`).
3. Under **Control/OSC/web**, click **Add**.
4. Configure:
   - **Control surface mode:** `OSC (Open Sound Control)`
   - **Pattern config:** `Default`
   - **Mode:** `Receive on UDP port`
   - **Listen port:** `8000`
5. Click **OK** and **Apply**.

---

#### 📌 2. REAPER Track & Marker Mapping

Question triggers route through **Track 3**, while game events route through **Tracks 33–36**:

| Track | Event / Scenario | Marker ID | Action |
| :--- | :--- | :---: | :--- |
| **Track 3** | Question 1 Audio | **20** | `Q1 Start / Cue` |
| **Track 3** | Question 2 Audio | **25** | `Q2 Start / Cue` |
| **Track 3** | Question 3 Audio | **26** | `Q3 Start / Cue` |
| **Track 3** | Question 4 Audio | **27** | `Q4 Start / Cue` |
| **Track 33** | Miss the Ghost | **21** | `Miss Sound Effect` |
| **Track 34** | Hit the Ghost | **22** | `Hit Sound Effect` |
| **Track 35** | Ghost Lose / Defeated | **23** | `Ghost Defeat Music` |
| **Track 36** | Victory Song | **24** | `Victory Fanfare` |

---

#### 💡 3. Audio & Lighting Synchronization Matrix

When an event triggers in Python, it dispatches OSC messages to both REAPER (`127.0.0.1:8000`) and grandMA3 (`192.168.254.252:8080`):

| Game Event | REAPER Track | REAPER Marker | grandMA3 Sequence |
| :--- | :---: | :---: | :--- |
| **Question 1** | Track 3 | Marker 20 | Sequence `93` |
| **Question 2** | Track 3 | Marker 25 | Sequence `94` |
| **Question 3** | Track 3 | Marker 26 | Sequence `95` |
| **Question 4** | Track 3 | Marker 27 | Sequence `96` |
| **Miss Ghost** | Track 33 | Marker 21 | Sequence `103` |
| **Hit Ghost** | Track 34 | Marker 22 | Sequence `104` |
| **Ghost Defeated** | Track 35 | Marker 23 | Sequence `105` |
| **Victory Song** | Track 36 | Marker 24 | Sequence `106` |

---

### 4.2 Lighting Cues Setup
The lights is used when players are in the zone of the ghosts, lights will light up so that players will know when to press the button to dispel the ghosts.

It communicates with the grandMA3 console using OSC network commands over UDP.

```python
GMA3_IP = "192.168.254.252"   # Replace with your grandMA3 console/laptop IP address
GMA3_PORT = 8080             # Default grandMA3 inbound OSC port
GMA3_ADDR = "/gma3/cmd"
```
```python
try:
    client = udp_client.SimpleUDPClient(GMA3_IP, GMA3_PORT)
    print(f"[LIGHTING] Connected to grandMA3 at {GMA3_IP}:{GMA3_PORT}")
except Exception as e:
    client = None
    print(f"[LIGHTING ERROR] Failed to initialize OSC client: {e}")
```
---

#### Game State & Arena Lighting

When the game state transitions through different phases, it triggers main global lighting looks across the arena:

| Game Phase | Trigger / Action | What the Lighting Console Does | Command Used |
| :--- | :--- | :--- | :--- |
| **Tutorial Complete / Game Start** | Player finishes tutorial; active gameplay begins. | Turns on **Sequence 1, Cue 1.0** (Green Wash) to fill the room. | `Goto Cue 1.0 Sequence 1` |
| **Wave 3 (Final Boss)** | Players clear Waves 1 & 2 and reach the final stage. | Starts the **Final Boss sequence**. | `Go+ Sequence 35` |
| **Game Victory / Mission Complete** | Players clear all target zones before time runs out. | Turns off all ghost lights & final boss light, then fires the **Victory Look**. | `Off Sequence 35`<br>`Off [All Ghost Sequences]`<br>`Go+ Sequence 36` |

```python
def trigger_final_ghost_light():
    """Triggers the lighting sequence for the Wave 3 Final Boss."""
    send_command(f"Go+ Sequence {FINAL_GHOST_SEQUENCE}")

def trigger_game_finish_light():
    """
    Kills the final boss sequence and all mapped ghost sequences,
    then triggers the game completion sequence.
    """
    # 1. Kills the Final Boss sequence explicitly
    send_command(f"Off Sequence {FINAL_GHOST_SEQUENCE}")
    
    # 2. Ensures all standard ghost sequences are off
    for seq_id in GHOST_SEQUENCES.values():
        send_command(f"Off Sequence {seq_id}")
        
    # 3. Triggers the Victory / Game Over Sequence
    send_command(f"Go+ Sequence {GAME_OVER_SEQUENCE}")
```

---

#### Ghost Target Spotlights

When a player physically enters an active ghost's target zone inside the arena, that ghost's spotlight sequence turns **ON**. Stepping out or dispelling the ghost turns the sequence **OFF**.

```python
GHOST_SEQUENCES = {
    0: 31,  # Ghost 0 (Bob)
    1: 32,  # Ghost 1 (Stewart)
    2: 37,  # Ghost 2 (Tim)
    3: 34,  # Ghost 3 (Kevin)
    4: 29,  # Ghost 4 (Carl)
    5: 33,  # Ghost 5 (Dave)
}

def set_ghost_light(ghost_index: int, turn_on: bool):
    """Triggers or turns off the specific Sequence mapped to a ghost."""
    seq_id = GHOST_SEQUENCES.get(ghost_index)
    if seq_id is not None:
        if turn_on:
            send_command(f"Go+ Sequence {seq_id}")
        else:
            send_command(f"Off Sequence {seq_id}")

```
This is a Demo how it will look like for Wave 1 and 2.
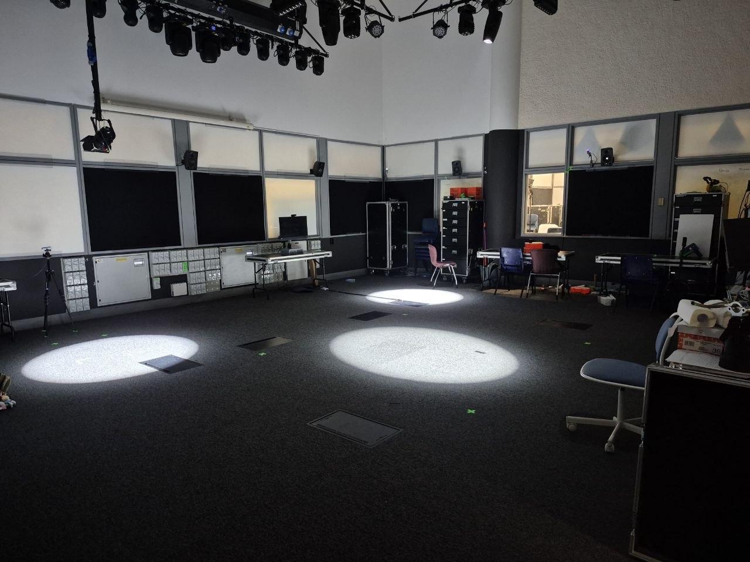
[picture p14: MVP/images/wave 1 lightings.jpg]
Wave 1 lightings

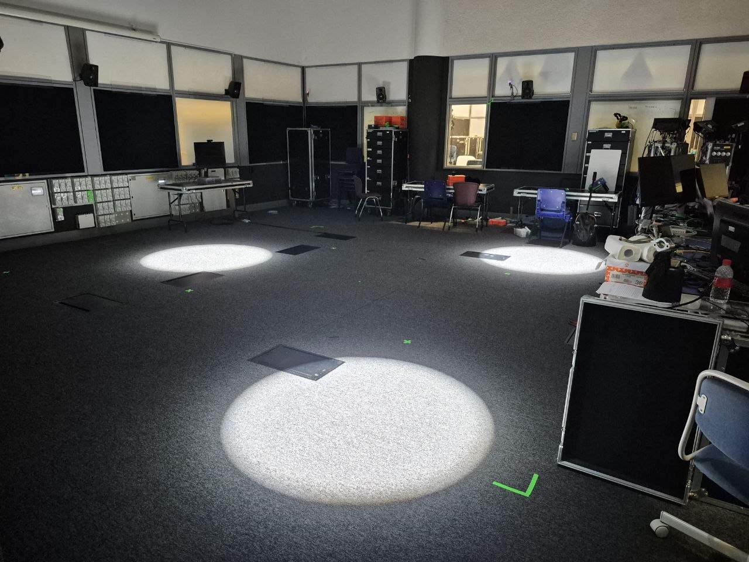
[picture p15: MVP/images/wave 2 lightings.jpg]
Wave 2 lightings


#### Ghost Sequence Mapping Table

| Target ID | Ghost Character | Target Zone Color | grandMA3 Sequence ID | Action on Walk-In | Action on Walk-Out / Dispel |
| :---: | :--- | :--- | :---: | :--- | :--- |
| **0** | **Bob** (Wave 1) | Yellow | `Sequence 31` | `Go+ Sequence 31` | `Off Sequence 31` |
| **1** | **Stewart** (Wave 1) | Bright Green | `Sequence 32` | `Go+ Sequence 32` | `Off Sequence 32` |
| **2** | **Tim** (Wave 1) | Orange | `Sequence 37` | `Go+ Sequence 37` | `Off Sequence 37` |
| **3** | **Kevin** (Wave 2) | Cyan / Light Blue | `Sequence 34` | `Go+ Sequence 34` | `Off Sequence 34` |
| **4** | **Carl** (Wave 2) | Pink / Purple | `Sequence 29` | `Go+ Sequence 29` | `Off Sequence 29` |
| **5** | **Dave** (Wave 2) | Hot Pink | `Sequence 33` | `Go+ Sequence 33` | `Off Sequence 33` |
| **6** | **Jerry** (Wave 3 / Boss) | Red / Pink | `Sequence 35` | `Go+ Sequence 35` | `Off Sequence 35` |

---

#### Quick Lighting Test Checklist

Use this checklist to troubleshoot or verify grandMA3 setup during arena configuration:

1. **Verify Network IP:** Ensure the lighting computer or console is set to static IP `192.168.254.252` and listening on Port `8080`.
2. **Check Command Path:** Confirm the console's OSC configuration accepts command-line OSC string payloads under `/gma3/cmd`.
3. **Manual Command Test:** Test target execution directly from the console command line:
   * **Turn On:** `Go+ Sequence 31` (Triggers Bob's spotlight)
   * **Turn Off:** `Off Sequence 31` (Clears Bob's spotlight)

## 5. Conditions For The Game
When playing a game, there is always a need for conditions so players can either win or lose the game.

There are 3 conditions to the game as well. Firstly, when tag is in the zone and button is pressed, the ghosts will be dispel. Secondly, when tag is not in zone but button is pressed, timer will add 5 seconds. Lastly, when tag is in zone but button is not pressed, nothing will happen.

```python
def handle_button_event(state, is_pressed):
        with state.lock:
            state.button_pressed = is_pressed
            
            # Only trigger hit detection on button PRESS down
            if is_pressed and not state.game_won and not state.game_lost and state.timer_active:
                hit_detected = False
                
                # STEP 1: Process tag hit checks for current wave ghosts
                for tag_id, tag in enumerate(state.tags):
                    if tag.filt_position is None:
                        continue
                    
                    for zi, ghost in enumerate(game_logic.Ghosts):
                        if ghost.get("active", True) and ghost.get("wave") == game_logic.CURRENT_WAVE:
                            if game_logic.ptInGhost(tag.filt_position, ghost):
                                print(f"\n🎯 DISPELLED: Tag {tag_id} hit Wave {game_logic.CURRENT_WAVE} Ghost [{ghost['label']}]!")
                                ghost["active"] = False
                                hit_detected = True
                                
                                # Turn OFF the individual light for this dispelled ghost
                                lighting.set_ghost_light(zi, turn_on=False)

                # STEP 2: Evaluate Wave Progression & Audio / Lighting Triggers
                if hit_detected:
                    state.time_left += 30.0
                    
                    # Trigger Ghost Kill sound in Reaper & L-ISA
                    if hasattr(app, 'audio_controller'):
                        app.audio_controller.trigger_alarm()
                    
                    # Check if all ghosts in the CURRENT wave are dispelled
                    wave_cleared = all(
                        not g.get("active", True) 
                        for g in game_logic.Ghosts 
                        if g.get("wave") == game_logic.CURRENT_WAVE
                    )
                    
                    if wave_cleared:
                        if game_logic.CURRENT_WAVE < 4:
                            game_logic.CURRENT_WAVE += 1
                            print(f"\n🌊 WAVE CLEARED! Transitioning to Wave {game_logic.CURRENT_WAVE}...")
                            
                            # Trigger Sequence when reaching Wave 3 (Final Boss)
                            if game_logic.CURRENT_WAVE == 3:
                                lighting.trigger_final_ghost_light()

                            root.after(0, app.force_instant_ui_refresh)
                        else:
                            state.game_won = True
                            state.timer_active = False 
                            print("\n🏆 !!! WIN CONDITION ACHIEVED !!! All arena grid sectors cleared! 🏆")
                            
                            # Kills final boss light and triggers victory sequence
                            lighting.trigger_game_finish_light()

                            root.after(0, app.force_instant_ui_refresh)
                    else:
                        root.after(0, app.force_instant_ui_refresh)
                else:
                    # Penalty for pressing button without hitting a ghost
                    state.time_left -= 5.0
```

### 5.1 Win Condition
To win the game, players must physically navigate the arena and **dispel all target ghosts across all 3 Waves** before the master countdown timer reaches zero.

---

#### Step-by-Step Victory Rules

1. **Active Wave Tracking:**
   * Players start at **Wave 1**.
   * Standing inside a ghost's target zone and pressing the tag button dispels that ghost.
   * Each time a ghost is dispelled, **+30 seconds** are added to the remaining timer as a reward.

```python
# Checks if the physical button press occurred inside an active ghost's radius
for zi, ghost in enumerate(game_logic.Ghosts):
    if ghost.get("active", True) and ghost.get("wave") == game_logic.CURRENT_WAVE:
        if game_logic.ptInGhost(tag.filt_position, ghost):
            ghost["active"] = False
            hit_detected = True
            lighting.set_ghost_light(zi, turn_on=False)

if hit_detected:
    state.time_left += 30.0  # +30s Reward
```
2. **Wave Progression:**
   * Once all ghosts in the active wave are cleared, the system automatically advances to the next wave:
     * **Wave 1 Cleared:** Progresses to Wave 2.
     * **Wave 2 Cleared:** Progresses to Wave 3 (Final Boss Stage).

```python
# Check if all ghosts in the current wave are inactive
wave_cleared = all(
    not g.get("active", True) 
    for g in game_logic.Ghosts 
    if g.get("wave") == game_logic.CURRENT_WAVE
)

if wave_cleared:
    if game_logic.CURRENT_WAVE < 4:
        game_logic.CURRENT_WAVE += 1
        if game_logic.CURRENT_WAVE == 3:
            lighting.trigger_final_ghost_light()  # Triggers Wave 3 Boss Light
```

3. **Final Victory Trigger:**
   * Clearing the final ghost in **Wave 3** immediately triggers the **WIN CONDITION**.

```python
# Triggered when Wave 3 is cleared
else:
    state.game_won = True
    state.timer_active = False 
    lighting.trigger_game_finish_light()
```

---

#### Hardware & System Victory Actions

The moment the final ghost is dispelled, `game_state.py` automatically executes the following actions across all connected hardware systems:

| Hardware System | System Action | What Happens in the Arena |
| :--- | :--- | :--- |
| **Countdown Timer** | **Freezes / Stops** | The timer halts immediately to lock in the players' final completion time. |
| **Arena Display HUD** | **Victory Banner** | Screen updates to render: `!!! WIN CONDITION ACHIEVED !!! Area Cleared!` |
| **Stage Lighting (grandMA3)** | **Victory Look** | Extinguishes all active ghost/boss spotlights (`Off Sequence 35`) and fires the **Victory Celebration Sequence** (`Go+ Sequence 36`). |
| **Spatial Audio (REAPER / L-ISA)** | **Mute / Audio Cue** | Triggers the final dispel snapshot, halts proximity tracking audio, and safely mutes overall track output via OSC commands. |

---

#### Penalty Logic

> [!WARNING]
> **Incorrect Button Presses:** Pressing the tag button while **outside** an active ghost target zone results in an immediate **5-second time penalty** deducted from the master timer.

```python
if not hit_detected:
    # Deduct 5 seconds if button pressed outside any target zone
    state.time_left -= 5.0
```

### 5.2 Lose Condition

The game is lost if the countdown timer reaches zero before every ghost in all three waves has been dispelled.

#### Timer mechanics

The timer lives in shared game state and only starts counting once the tutorial is completed:

```python
self.time_left = 150.0       # 150-second countdown
self.timer_active = False    # Stays paused until tutorial is dismissed
```

Once active, `display.py`'s render loop decrements it every frame based on real elapsed time (not a fixed tick), so it stays accurate regardless of frame rate:

```python
if self.state.timer_active and not self.state.game_won and not self.state.game_lost:
    delta = now - self.state.last_time
    self.state.time_left -= delta
    self.state.last_time = now

    if self.state.time_left <= 0:
        self.state.time_left = 0
        self.state.game_lost = True
        self.state.timer_active = False
```

#### What affects the clock

| Action | Effect |
|---|---|
| Dispelling a ghost (button press inside a zone) | **+30 seconds** |
| Pressing the button outside any active zone | **−5 seconds** (penalty for a wasted/wrong press) |

This means the timer isn't purely a countdown — good play actively buys more time, so the lose condition is really "run out of misses and time before clearing all ghosts."

#### On lose

When `time_left` hits zero:

- `state.game_lost = True` and `state.timer_active = False` are set, freezing the game
- The arena canvas title updates immediately:
  ```python
  self.canvas.itemconfig(self.title_text, text="MISSION FAILED — OUT OF TIME!", fill="#ff0000")
  ```
- The same message/color is re-applied by `force_instant_ui_refresh()` if triggered from elsewhere, so the fail state is consistent no matter what path set it
- The timer HUD window turns red (`#ff5252`) once under 30 seconds remaining, giving players a visual warning before the loss actually happens:
  ```python
  timer_color = "#ff5252" if (self.state.time_left < 30.0 and self.state.timer_active) else "#00ffff"
  ```
- Once `game_lost` is `True`, `main.py`'s button handler stops processing hit detection entirely — further button presses have no effect on game state

## 6. Final Outcome

 📋 Final Setup & Outcome Summary — Ghost Hunting Game

A wrap-up summary of the complete game setup, how a session plays out end-to-end, and the two possible final outcomes.

---

### 6.1 Setup Overview

| Layer | Component | Status |
|---|---|---|
| **Positioning hardware** | 6× fixed UWB anchors + per-player UWB tags | Configured via `game_logic.ANCHORS` |
| **Player device ("gun")** | Raspberry Pi + UWB tag (UART) + push button (GPIO 18) | `pi_transmitter.py` |
| **Network transport** | OSC over UDP, Pi → Laptop | Port `5005` (`--port`) |
| **Position engine** | Trilateration + Kalman filter | `network.py`, `trilateration.py` |
| **Game engine** | Wave/ghost state, hit detection, timer | `game_logic.py`, `game_state.py`, `main.py` |
| **Spectator display** | Live arena map, tag table, timer HUD, tutorial | `display.py`, `tutorial_ui.py` |
| **Lighting** | grandMA3 via OSC | `lighting.py` |
| **Audio** | REAPER + L-ISA via OSC | `reaper.py` |

**End-to-end flow:** UWB tags measure distance → Pi reads UART + button, forwards via OSC → laptop trilaterates position → game logic checks position against active ghost zones → display updates live → button press attempts a dispel → lighting + audio react → timer and wave state update → repeat until win or loss.

---

### 6.2 Session Flow (Start to Finish)

1. **Launch** — `main.py` starts the OSC server, opens the arena display, and waits
2. **Tutorial** — players complete the 4-step onboarding panel; timer stays paused (`timer_active = False`) until this finishes
3. **Hunt begins** — timer starts at `150.0s`, green "wash" lighting cue fires
4. **Wave 1 → 2 → 3** — players track ghosts via proximity beeping, walk into zones, and press the button to dispel; each successful dispel is `+30s`, each wasted press is `−5s`
5. **Round ends** — either all 3 waves are cleared (**win**) or the timer hits `0` first (**loss**)

---

### 6.3 Final Outcomes

#### 🏆 Win
- Fires when the **last ghost of wave 3** is dispelled
- `game_won = True`, timer stops instantly at whatever time remains
- `lighting.trigger_game_finish_light()` clears all ghost/boss sequences and triggers the **Victory** cue on grandMA3
- Arena title switches to green: `"GAME OVER — AREA CLEARED! YOU WIN!"`

#### ☠️ Lose
- Fires when `time_left` reaches `0` before all waves are cleared
- `game_lost = True`, timer freezes at `0.0`
- Arena title switches to red: `"MISSION FAILED — OUT OF TIME!"`
- **No lighting or audio cue currently fires on loss** — this is the one asymmetry between the two outcomes

#### After either outcome
- Button presses stop affecting the game (`handle_button_event` checks `not game_won and not game_lost`)
- The arena title and timer HUD simply freeze on-screen showing final state — there is no dedicated results/summary screen
- No stats are persisted anywhere (no logging of waves cleared, hit/miss counts, or time remaining/overrun)
- Returning to a fresh round currently requires restarting the app — `game_won`, `game_lost`, `time_left`, and ghost `active` flags are not reset in-session

---

### 6.4 Setup Checklist

Use this to confirm a venue is ready before a session:

- [ ] All 6 anchor coordinates in `game_logic.ANCHORS` match the physical arena
- [ ] `VIEW_BOUNDS` in `game_logic.py` covers the full playable area
- [ ] Each gun's `LAPTOP_IP` in `pi_transmitter.py` points to the current laptop IP
- [ ] `--port` on the laptop matches `PORT` in every gun's config
- [ ] `GMA3_IP` / `GMA3_PORT` in `lighting.py` reachable, and `GHOST_SEQUENCES` / `FINAL_GHOST_SEQUENCE` / `GAME_OVER_SEQUENCE` match the grandMA3 show file
- [ ] `REAPER_IP` / `LISA_IP` in `reaper.py` reachable, and marker/action IDs match the current REAPER project
- [ ] Buttons debounced and tested on all guns (`bounce_time=0.2`)
- [ ] Tutorial content reviewed and up to date (`tutorial_ui.py`)
- [ ] `--tags` set to the correct number of players for the session

### 6.5 Gameplay in Action
This photo below shows the player should be positioned in gameplay holding the handheld gun (tag + button), with a mounted anchor visible behind them
PLAYER

---
### 6.6 Demo Video
This video recording below shows the screen recording of the game
[MVP RECORDING.zip](https://github.com/user-attachments/files/30385286/MVP.RECORDING.zip)

The recording below shows a screen capture of gameplay in action
https://drive.google.com/file/d/1WY7LVYyNPCTMdVvlaRalucw68OrxDq7S/view?usp=drive_link

### 7. Repository Structure
```
EGL314TeamD/
└── MVP/
    ├── 3dPrintedFiles/
    │   └── 3D Print Gun/
    ├── GhostGameSoundV1/
    ├── GhostGameSound/
    ├── GhostGame/
    ├── UWB&Reaper/
    ├── images/
    ├── imgAnchors&Tags/
    └── README.md
```

### 8. System Architecture
```mermaid
graph TD
    %% 1. Top Level Hardware & Sensor Node
    A[AI Thinker UWB Kit] -->|UART| B[Sensor Pi -> uart.py]
    
    %% 2. Core Game Logic Node
    B -->|OSC| C[Laptop -> game.py]
    
    %% 3. Subsystem Split
    C -->|OSC| D[REAPER]
    C -->|OSC| E[GrandMA3]
    
    %% 4. Lighting Subsystem
    E -->|Wireless DMX| F[Lighting Fixtures]
    
    %% 5. Audio Subsystem Pipeline
    D -->|Dry digital audio| G[L-ISA Processor]
    H[L-ISA Controller] -->|Control data| G
    G -->|Rendered audio via Dante| I[Yamaha QL1]
    I -->|Dante| J[Yamaha Amplifier]
    J -->|Amplified analog audio| K[Yamaha Speakers]

    %% Styling & Customizations
    style A fill:#1f2937,stroke:#6b7280,stroke-width:1px,color:#fff
    style B fill:#1f2937,stroke:#6b7280,stroke-width:1px,color:#fff
    style C fill:#1f2937,stroke:#6b7280,stroke-width:1px,color:#fff
    style D fill:#1f2937,stroke:#6b7280,stroke-width:1px,color:#fff
    style E fill:#1f2937,stroke:#6b7280,stroke-width:1px,color:#fff
    style F fill:#1f2937,stroke:#6b7280,stroke-width:1px,color:#fff
    style G fill:#1f2937,stroke:#6b7280,stroke-width:1px,color:#fff
    style H fill:#1f2937,stroke:#6b7280,stroke-width:1px,color:#fff
    style I fill:#1f2937,stroke:#6b7280,stroke-width:1px,color:#fff
    style J fill:#1f2937,stroke:#6b7280,stroke-width:1px,color:#fff
    style K fill:#1f2937,stroke:#6b7280,stroke-width:1px,color:#fff

    linkStyle default stroke:#9ca3af,stroke-width:1px,color:#9ca3af
```

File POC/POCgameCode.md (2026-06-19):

# POC game code
This guide includes:
1. [Base of game](#1-base-game)
2. [Button input](#2-rapberry-pi-button-input)
3. [Ghost dispelling mechanic](#3-ghost-dispelling-mechanic)
4. [Winning condition](#4-win-condition)
5. [Lose condition](#5-lose-condition)
6. [Proximity beeping mechanic](#6-proximity-beeping-mechanic)  

Back to [README.md](README.md)

## 1. Base game  
The game consists of three ghosts.  
The information for each ghost is stored as a **dictionary** within a **list**, named 'Ghosts' as follows:
```python
Ghosts = [
    {
        "center": (0.25, 0.625),
        "radius": 0.15,
        "min_radius": 0.10,
        "color": "#ffff00",
        "label": "Bob",
        "active": True,
    },
    {
        "center": (0.75, 1.0),
        "radius": 0.15,
        "min_radius": 0.10,
        "color": "#fff700",
        "label": "Stewart",
        "active": True,
    },
    {
        "center": (0.75, 0.25),
        "radius": 0.15,
        "min_radius": 0.10,
        "color": "#fff700",
        "label": "Kevin",
        "active": True,
    },
]
```   

The function ptInGhost determines where the tag is from the ghost by using Pythagoras, and enter/exit events only fire once at the moment of crossing.  
```python
def ptInGhost(point, ghost):
    if point is None:
        return False
    px, py = point
    zx, zy = ghost["center"]
    r = ghost["radius"] + GhostHitTol
    dx = px - zx
    dy = py - zy
    return (dx * dx + dy * dy) <= (r * r)
```
Both of these allow the game to recognise where the ghosts and tags are in relation to one another and the anchors.  
This is then visualised in __init __, where mpatches.Circle patches added to the axes with dashed edges and ghost label text centred inside:
```python
self.ghost_patches = {}
        for zi, ghost in enumerate(Ghosts):
            cx, cy = ghost["center"]
            circle = mpatches.Circle((cx, cy), ghost["radius"], fill=False, linewidth=3, linestyle="-.", edgecolor=ghost["color"], alpha=0.9)
            self.ax_plot.add_patch(circle)
            txt = self.ax_plot.text(cx, cy, ghost["label"], color=ghost["color"], fontsize=11, ha="center", va="center", weight="bold")
            self.ghost_patches[zi] = (circle, txt)
```

## 2. Rapberry Pi button input 

### Pin Declaration & GPIO Setup

```python
BUTTON_PIN = 27
GPIO.setmode(GPIO.BCM)
GPIO.setup(BUTTON_PIN, GPIO.IN, pull_up_down=GPIO.PUD_UP)
```

This sets GPIO pin 27 as an input with an internal pull-up resistor, meaning the pin reads HIGH normally and goes LOW when the button is pressed.  

### Callback Function:

```python
def pin_edge_callback(channel):
    is_pressed = not GPIO.input(channel)
    with state.lock:
        state.button_pressed = is_pressed
        ...
```

This function runs automatically whenever the button is pressed or released. `not GPIO.input(channel)` flips the logic — since the pin is pull-up, a LOW signal (button pressed) becomes `True`.

### Edge Detection Registration

```python
GPIO.add_event_detect(BUTTON_PIN, GPIO.FALLING, callback=pin_edge_callback, bouncetime=200)
```

This is what actually "listens" for the button. `GPIO.FALLING` means it triggers on the HIGH→LOW transition (i.e. the moment the button is pressed down). The `bouncetime=200` is a 200ms debounce filter to prevent a single press from firing multiple times.

### Cleanup on Exit

```python
GPIO.cleanup()
```

At the very end in the `finally` block, this releases the GPIO pins safely when the program closes.

## 3. Ghost Dispelling Mechanic
When Player is in the vicinity of a ghost and presses the button, the ghost will be dispelled.  

When button is pressed
``` python
 def pin_edge_callback(channel):
        is_pressed = not GPIO.input(channel)
        with state.lock:
            state.button_pressed = is_pressed

            # --- FORCE IMMEDIATE DEACTIVATION ON PRESS ---
            if is_pressed:
                for tag_id, tag in enumerate(state.tags):
                    if tag.filt_position is None:
                        continue
```
And tag is in the zone where one of the ghosts is,
```python
for zi, ghost in enumerate(Ghosts):
                        if ghost.get("active", True):
                            # Check if this tag is inside this ghost right now
                            if ptInGhost(tag.filt_position, ghost):
                                print(f"\n🎯 HIT! Tag {tag_id} dispelled {ghost['label']}!")
                                ghost["active"] = False
```
the ghost will be removed by changing the ghost's active state to False.

This is where the loop will visually erase the ghosts from the screen during the user interface frame refresh loop.
```python
        self.root.after(40, self.update_loop)

for zi, ghost in enumerate(Ghosts):
            if not ghost.get("active", True) and zi in self.ghost_patches:
                circle, txt = self.ghost_patches[zi]
                try:
                    circle.remove()
                    txt.remove()
                except ValueError:
                    pass
                del self.ghost_patches[zi]
```

## 4. Win Condition
For the player to win, they must first carry the BU03 tag (a tracking device) and button.  
The player must both be in the vicinity of the ghost and press the button to dispel the ghost.  
Clear all three ghosts within the allocated time to win.

### Game Matrix
Firstly, the game matrix identifies if the tag is in the ghost zone.
```python
for zi, ghost in enumerate(Ghosts):
                    if ghost.get("active", True):
                        if ptInGhost(tag.filt_position, ghost):
                            current_ghosts.add(zi)

                tag.ghosts_inside = {zi for zi in current_ghosts if Ghosts[zi]["active"]}

                for zi, ghost in enumerate(Ghosts):
                    if ghost.get("active", True):
                        is_in_zone = ptInGhost(tag.filt_position, ghost)
```

Secondly, it sets the condition the player has to achieve to win the game.  

1. If button is pressed and tag is in the zone of the ghosts,
```python
 # Condition 1: Button is pressed AND tag is inside the ghost zone
                        if state.button_pressed and is_in_zone:
                            print(f"\n=== SUCCESS === Tag {tag_id} dispelled Ghost: {ghost['label']}!")
                            ghost["active"] = False
```
ghosts will be dispelled and zone will be removed.

2. Or, if button is pressed and tag is not in the zone of the ghosts,
```python
                        # Condition 2: Button is pressed AND tag is NOT inside the ghost zone
                        elif state.button_pressed and not is_in_zone:
                            pass # Ghost remains unaffected 
```
ghosts will remain.

3. Else if button is not pressed and tag is in the zone of the ghosts,
```python
# Condition 3: Button is NOT pressed AND tag is inside the ghost zone
                        elif not state.button_pressed and is_in_zone:
                            current_ghosts.add(zi) # Ghost remains, mark as occupying zone
```
ghosts will remain.

Lastly, after all ghosts is removed within the timeframe, player wins the game.
```python
                tag.ghosts_inside = {zi for zi in current_ghosts if Ghosts[zi]["active"]}
                
# Check for Win Condition (Are all ghosts turned off?)
                if all(not g.get("active", True) for g in Ghosts):
                    state.game_won = True
                    print("\n🏆 !!! CONGRATS!!! U WIN!!! ALL GHOSTS CLEARED!!! 🏆")
```

## 5. Lose Condition
The game starts with a 120-second countdown timer.  
Each time the player successfully dispels a ghost by pressing the correct button while inside the correct zone, 30 seconds are added to the remaining time.  
  
If the player attempts to dispel a ghost outside the designated zone, 5 seconds are deducted from the remaining time.  
The player will lose when the countdown timer reaches 0 seconds before all ghosts are dispelled.

### 120-Second Countdown from Game Start

```python
# ---------------------------------------------------------------------------
# Timer Configuration
# ---------------------------------------------------------------------------
TIMER_START_SECONDS  = 120   # starting countdown
TIMER_BONUS_CAPTURE  = 30    # seconds added on successful ghost capture
TIMER_PENALTY_MISS   = 5     # seconds deducted on wrong button press
```

```python
self.timer_end = time.time() + TIMER_START_SECONDS  # NEW: absolute deadline
```

**Where:** `SharedState.__init__()` inside the `SharedState` class.

The timer is not a simple counter. Instead, `timer_end` stores an **absolute future timestamp** — the current time plus 120 seconds. The remaining time is always computed as `timer_end - time.time()`, which means all bonuses and penalties just shift this deadline forward or backward.

### Additional 30 Seconds on Successful Ghost Dispel

This happens in **two places** — once in the OSC handler (continuous tracking), and once in the GPIO button callback (instant press detection).

### In the OSC handler (`make_osc_handler`):

```python
# Condition 1: Button is pressed AND tag is inside the ghost zone
if state.button_pressed and is_in_zone:
    print(f"\n=== SUCCESS === Tag {tag_id} dispelled Ghost: {ghost['label']}!")
    ghost["active"] = False
    # Bonus time for successful capture
    state.timer_end += TIMER_BONUS_CAPTURE
    print(f"[timer] +{TIMER_BONUS_CAPTURE}s bonus — new remaining: {state.timer_end - time.time():.1f}s")
```

### In the GPIO button callback (`pin_edge_callback`):

```python
if ptInGhost(tag.filt_position, ghost):
    print(f"\n🎯 HIT! Tag {tag_id} dispelled {ghost['label']}!")
    ghost["active"] = False
    hit_any_ghost = True
    # Bonus time for successful capture
    state.timer_end += TIMER_BONUS_CAPTURE
    print(f"[timer] +{TIMER_BONUS_CAPTURE}s bonus — new remaining: {state.timer_end - time.time():.1f}s")
```
When a successful hit is confirmed (button pressed + player is inside the ghost's zone), `TIMER_BONUS_CAPTURE` (30) is added directly to `timer_end`, pushing the deadline 30 seconds further into the future.

### -5 Seconds Deducted on a Missed Button Press

```python
# NEW: penalty if button pressed but no ghost was hit
if not hit_any_ghost:
    state.timer_end -= TIMER_PENALTY_MISS
    remaining = state.timer_end - time.time()
    print(f"\n❌ MISS! No ghost hit — -{TIMER_PENALTY_MISS}s penalty. Remaining: {remaining:.1f}s")
```

**Where:** Still inside `pin_edge_callback`, immediately after the ghost-hit loop.

If the button is pressed but `hit_any_ghost` remains `False` (the player wasn't inside any active ghost zone), `TIMER_PENALTY_MISS` (5) is **subtracted** from `timer_end`, bringing the deadline 5 seconds closer.

### Player Loses When Timer Reaches 0

```python
# --- TIMER EXPIRY CHECK (lose condition) ---
with self.state.lock:
    time_remaining = self.state.timer_end - now
    already_lost   = self.state.game_lost
    already_won    = self.state.game_won

if not already_won and not already_lost and time_remaining <= 0:
    with self.state.lock:
        self.state.game_lost = True
    print("\n💀 TIME'S UP — GAME OVER! You lose! 💀")
```

**Where:** `ViewerApp.update_loop()`, which runs every ~66ms via `root.after(66, self.update_loop)`.

Every UI refresh cycle, `time_remaining` is recalculated. The moment it hits zero or below (and the game hasn't already been won), `game_lost` is set to `True`. The display then updates accordingly:

```python
elif already_lost:
    self.timer_text.set_text("TIME'S UP!")
    self.timer_text.set_color("#ff0000")
```

```python
elif self.state.game_lost:
    self.ax_plot.set_title("GAME OVER — TIME'S UP! YOU LOSE!", color="#ff0000", fontsize=16, weight="bold")
```

---

### Summary Table

| Event | Code Constant | Effect on `timer_end` | Location |
|---|---|---|---|
| Game starts | `TIMER_START_SECONDS = 120` | Set to `now + 120` | `SharedState.__init__()` |
| Ghost dispelled (hit) | `TIMER_BONUS_CAPTURE = 30` | `+= 30` | `pin_edge_callback` / `make_osc_handler` |
| Button pressed, no ghost hit | `TIMER_PENALTY_MISS = 5` | `-= 5` | `pin_edge_callback` |
| Timer reaches 0 | — | `game_lost = True` | `ViewerApp.update_loop()` |

## 6. Proximity beeping mechanic
In order for players to decipher where ghosts are without a screen explicitly showing where the ghosts are, sound cues are added in order to hint at the location of the ghosts. 
   
4 different levels of beeping ranging in frequency will play depending on the distance of the player tag from the nearest ghost:

| Distance threshold | Cue |
| -- | -- |
| 0.0 | Cue 4 ( Fastest) |
| 0.25 | Cue 3 |
| 0.625 | Cue 2 |
| 1.0 | Cue 1 (Slowest)|
  
The faster the beeping, the closer the player is.   
Multiplay and Python OSC will be used to facilitate this mechanic in order for it to be synchronised with the game.

### Multiplay Address and Port

First, the Multiplay IP address and port are defined in the game's code:
```python
MULTIPLAY_IP   = "192.168.254.173"   # IP of the Multiplay machine
MULTIPLAY_PORT = 5005                # OSC UDP port Multiplay listens on
```
*Port must correspond to what is established in Multiplay OSC Control settings.  
Details written in [software setup](softwareSetup.md).

### Establishing Multiplay cue commands and corresponding radii

Next, the information for the sound cue and its threshold is defined here as a list:
```python
SOUND_CUE_THRESHOLDS = [
    (0.0,   "/cue/4/go"),   # right on the ghost  (hit tolerance)
    (0.25,  "/cue/3/go"),   # very close
    (0.625, "/cue/2/go"),   # medium range
    (1.0,   "/cue/1/go"),   # far away
]
```

This allows the code to be able to retrieve information for each distance from this list consistently without having to manually type it in every time.

The function 'nearest_ghost_distance' returns the minimum distance from the tag (point) to the centre of any active ghost:
```python
def nearest_ghost_distance(point):
    active = [g for g in Ghosts if g.get("active", True)]
    if not active:
        return float("inf")
    return min(dist_to_ghost(point, g) for g in active)
```
This is so that the code is able to discern the distance and thus which cue to play.  

```python
def cue_for_distance(distance):
    for threshold, address in SOUND_CUE_THRESHOLDS:
        if distance <= threshold:
            return address
    return None
```

cue_for_distance checks if the tag is within the cue thresholds stated above, then returns the Multiplay address written in SOUND_CUE_THRESHOLDS if it is, and None if it isn't.  

### MultiplayClient Class

Within the MultiplayClient class, there are 3 functions, '__init __', 'stop_all', and 'trigger'.
```python
class MultiplayClient:
    def __init__(self, ip: str, port: int):
        self._client = SimpleUDPClient(ip, port)
        print(f"[multiplay] OSC client initialised → {ip}:{port}")
```
__init __ initialises the Multiplay pythonOSC SimpleUDPClient for triggering Multiplay cues, creating a shared instance at startup and re-using it across all tags.  
  
Next, stop_all stops every currently active cue in Multiplay (/cue/all/stop).
```python
    def stop_all(self):
        try:
            self._client.send_message("/cue/all/stop", [])
            print("[multiplay] all cues stopped")
        except Exception as exc:
            print(f"[multiplay] stop_all failed: {exc}")
```
  
Finally, trigger stops all active cues, then immediately fires the requested cue.  
Stopping first guarantees no two proximity cues ever overlap, regardless of how Multiplay's own looping or auto-follow is configured.  

```python
    def trigger(self, address: str):
        try:
            self._client.send_message("/cue/all/stop", [])
            self._client.send_message(address, [])
            print(f"[multiplay] stopped all → cue sent: {address}")
        except Exception as exc:
            print(f"[multiplay] send failed ({address}): {exc}")
```

### Application in Game's Matrix

Within the game's main logic, these functions are applied like so:
```python
if multiplay_client and not state.game_won and not state.game_lost:
    dist = nearest_ghost_distance(tag.filt_position)
    new_cue = cue_for_distance(dist)
    if new_cue != tag.last_cue:
        if new_cue is not None:
            multiplay_client.trigger(new_cue)
        else:
            multiplay_client.stop_all()
        tag.last_cue = new_cue
```
It first checks if the game is still running by using an if statement to verify the game state is not won or lost, so that it will only send cues while the game is still running.  
stop_all() is called inside trigger() before the new cue fires, so overlaps are impossible.

---
Back to [README.md](README.md)

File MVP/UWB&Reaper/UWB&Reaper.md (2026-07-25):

## UWB Tracking and Immersive Audio System

### Anchor and Tag Configuration

The Ghost Game uses a UWB-based positioning system to track the player's movement within the game area.

Six UWB anchors were positioned around the designated play area. A laser distance measurer was used to measure and verify the distances between the anchors, ensuring that the physical positions of the anchors were accurately configured.

Accurate anchor placement is important because the system uses the measured distances between the anchors and the UWB tag to calculate the player's position within the tracking area.

After configuring the six anchors, a UWB tag was configured to track the player within the anchor area. The tag continuously communicates with the anchors, allowing the system to track the player's real-time location.

This tracking system forms the foundation of the Ghost Game. The player's calculated position is used to determine their distance from virtual ghosts placed within the game environment. Based on the player's proximity to a ghost, different audio, lighting, and gameplay responses can be triggered.

#### UWB Anchor Configuration Showcase

This is an Anchor, which is 1 of 6 that are mounted on a 3D print above head-height level to prevent any obstructions.

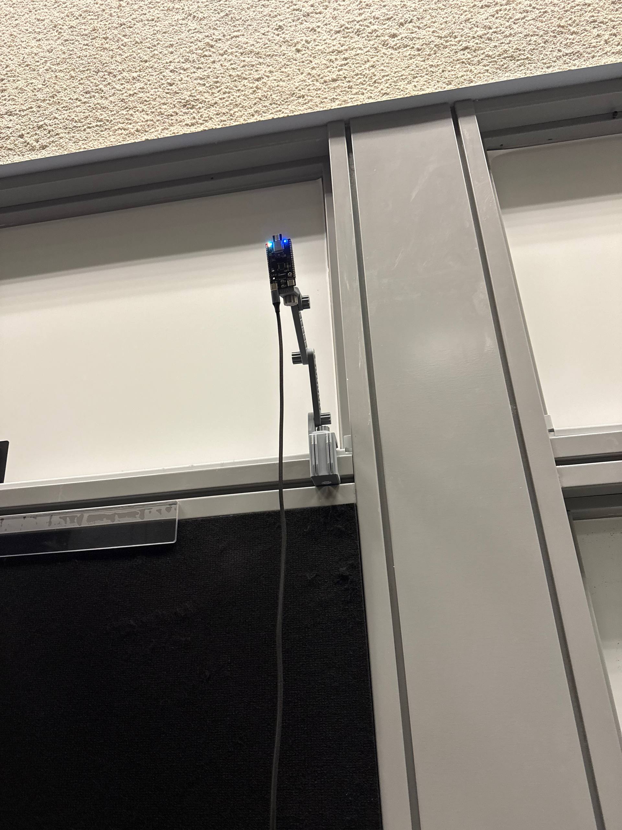
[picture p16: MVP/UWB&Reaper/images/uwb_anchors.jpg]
UWB Anchor Configuration


[Click this link](https://makerworld.com/en/models/2815216-heavy-duty-gravity-phone-mount-articulated-arm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) to go to the 3D print used for this documentation.

---

### REAPER Audio Integration

To create the audio system for the Ghost Game, a dedicated `reaper.py` module was developed as part of the `GhostGame` codebase.

The Python game system communicates with REAPER using OSC (Open Sound Control). The player's distance from a ghost is continuously monitored by the game, and different audio responses are triggered depending on the player's proximity.

The warning beep becomes faster as the player gets closer to a ghost, creating a more immersive and suspenseful gameplay experience.

The proximity system is divided into different stages:

- **Far Distance** – Slow warning beeps
- **Medium Distance** – Faster warning beeps
- **Close Distance** – Fast warning beeps
- **Ghost Interaction** – A separate audio event is triggered when the ghost is successfully eliminated

The `reaper.py` module sends OSC commands to REAPER to trigger the appropriate audio events. This allows the gameplay system to control the audio system in real time based on the player's position.

Using OSC communication, the Python game system and REAPER operate as separate systems while still communicating with each other over the network.

#### REAPER Track Configuration

The REAPER project was configured with multiple audio tracks to support the Ghost Game's proximity-based audio system. Different tracks were used for the various beeping stages and gameplay events.

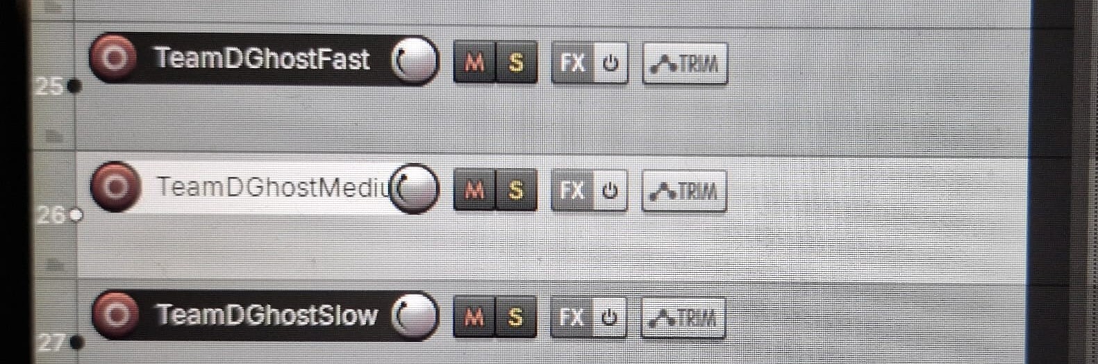
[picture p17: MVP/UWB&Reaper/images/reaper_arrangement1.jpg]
REAPER Audio Tracks


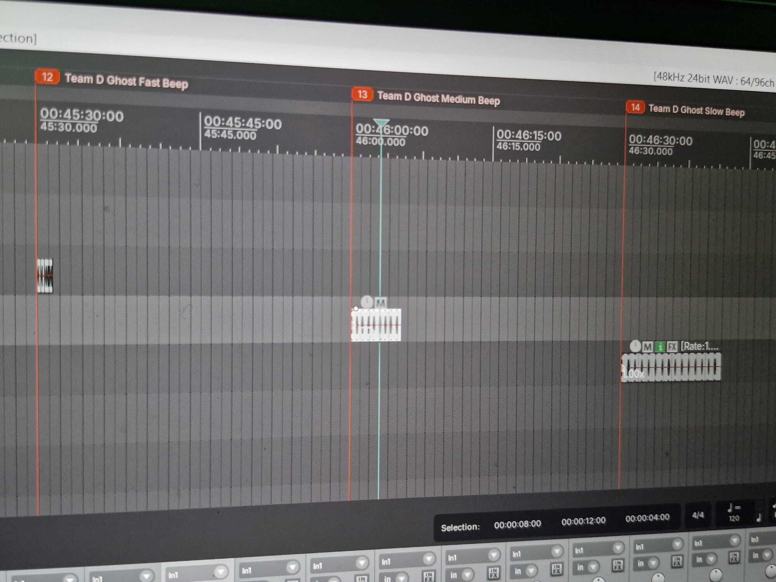
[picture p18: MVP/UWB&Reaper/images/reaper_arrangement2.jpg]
REAPER Audio Arrangement


---

### L-ISA Immersive Audio Integration

L-ISA was also integrated into the Ghost Game to provide a more immersive spatial audio experience.

The system uses 12 loudspeakers to create a larger and more immersive sound field for the player. This allows the audio system to provide greater spatial coverage compared to a conventional stereo setup.

The Python game system communicates with the L-ISA system using OSC commands. Different audio snapshots can be triggered based on the current gameplay state and the player's proximity to a ghost.

For example, different L-ISA audio states can be triggered for:

- Slow ghost proximity warning
- Medium ghost proximity warning
- Fast ghost proximity warning
- Ghost elimination

By combining UWB real-time tracking, REAPER audio playback, OSC communication, and L-ISA spatial audio, the Ghost Game creates an immersive audio experience where the sound system responds dynamically to the player's movement.

The 12-speaker setup helps create a more immersive environment by allowing audio to be distributed around the player. This enhances the feeling that ghosts are present within the surrounding environment and allows the audio system to become an important part of the gameplay experience.

#### L-ISA System Showcase

### L-ISA Controller Software

The L-ISA Controller software was used to create and manage the surround sound experience for the Ghost Game. It allows audio sources to be positioned and controlled within a spatial sound field, enabling sound to be distributed across the 12-speaker system.

Different audio configurations were saved as **snapshots**, with each snapshot representing a specific audio state or surround sound position. These snapshots could then be recalled during gameplay to change the audio experience based on the player's proximity to a ghost.

For example, different snapshots were used for slow, medium, and fast ghost proximity warnings, as well as specific gameplay events such as eliminating a ghost. This allowed the surround sound environment to respond dynamically to the player's movement and actions within the game.

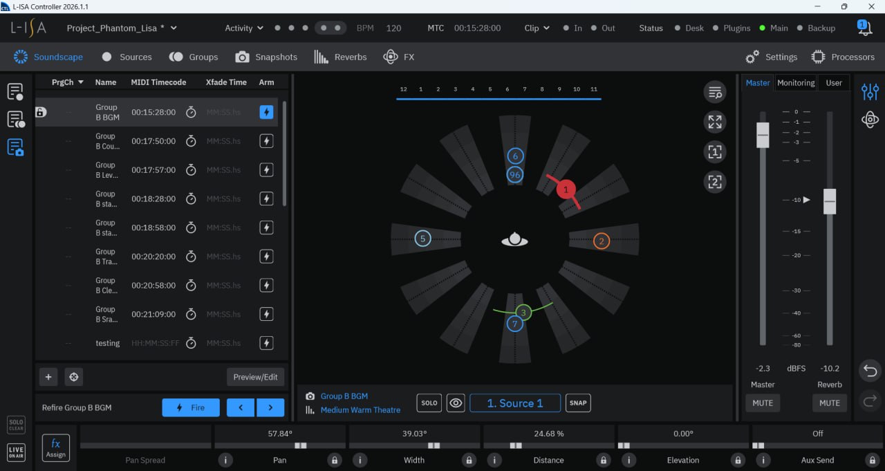
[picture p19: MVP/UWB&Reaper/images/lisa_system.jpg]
L-ISA Immersive Audio System


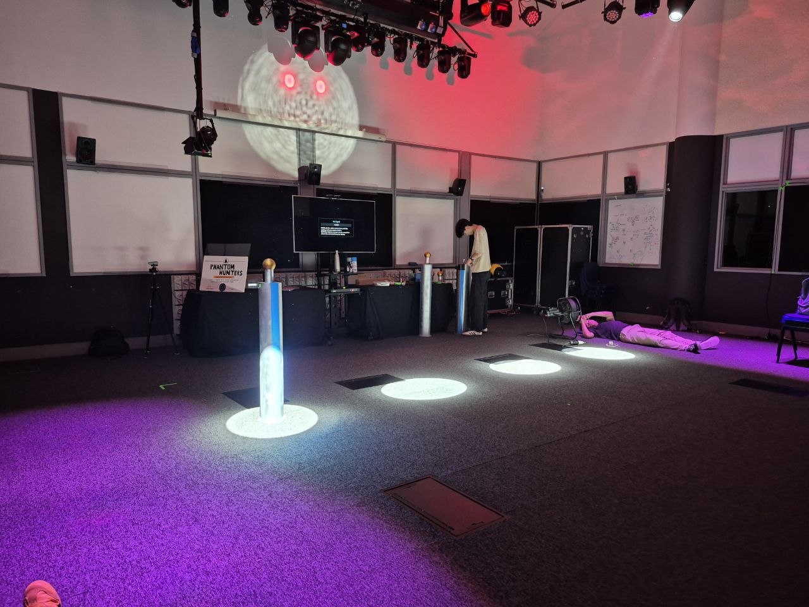
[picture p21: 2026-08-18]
Final/images/Q3.jpg

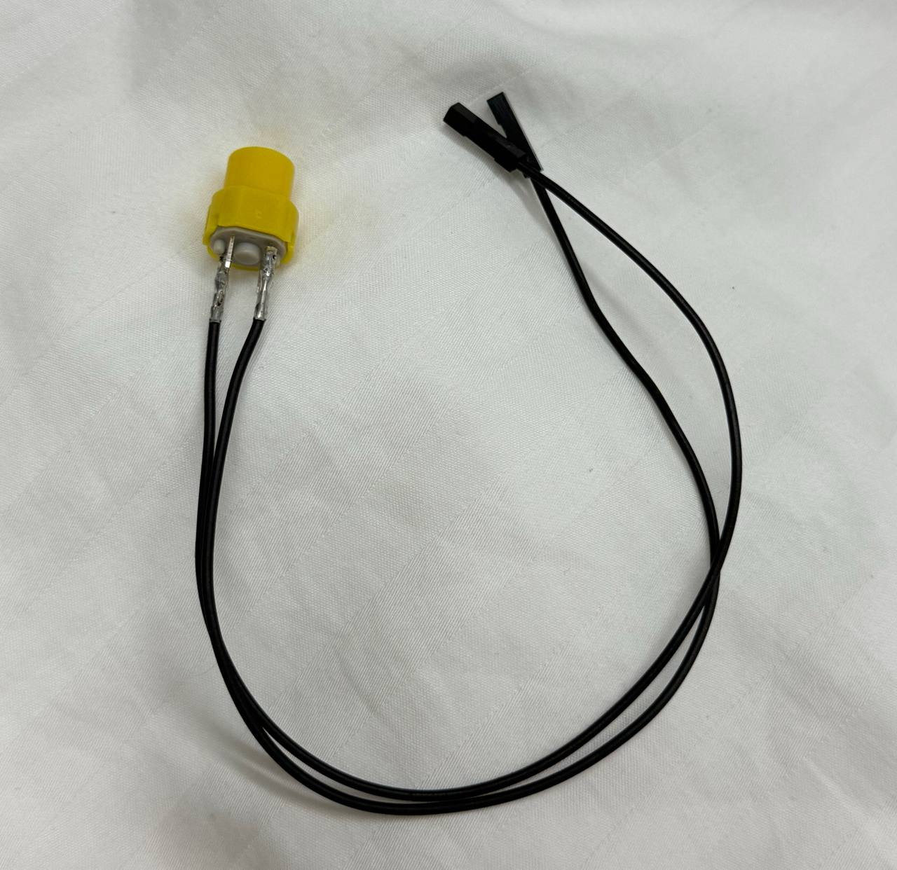
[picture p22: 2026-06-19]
images/buttonWire.jpg

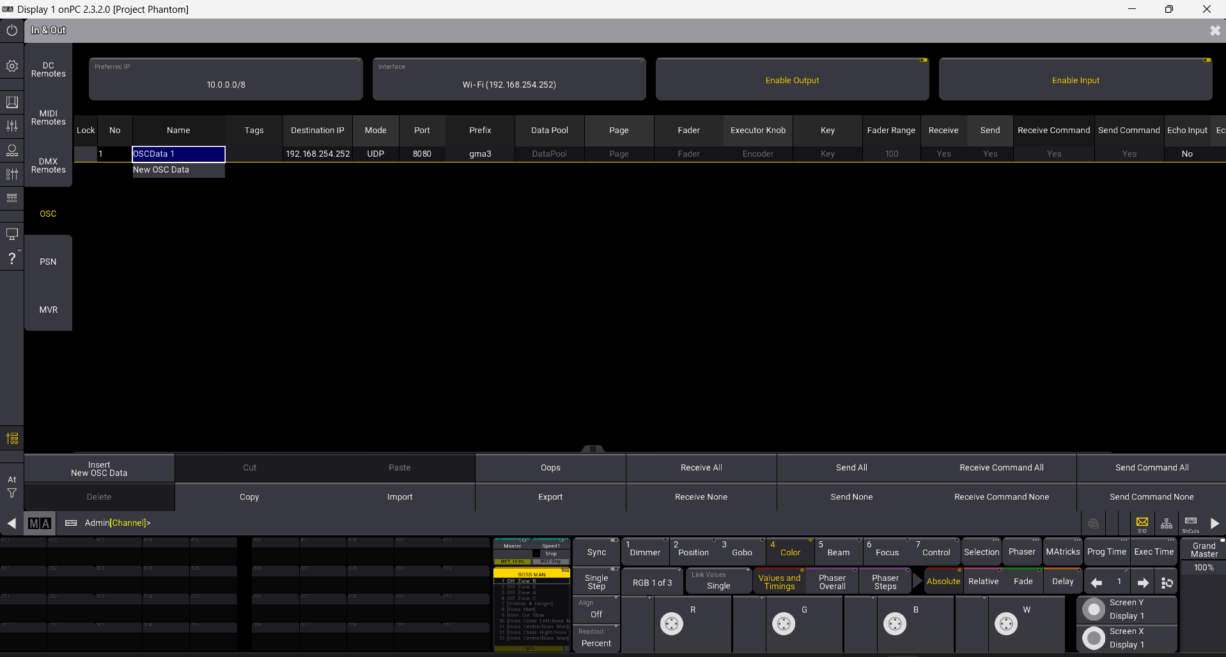
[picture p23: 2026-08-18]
Final/images/OSC LIGHT.png

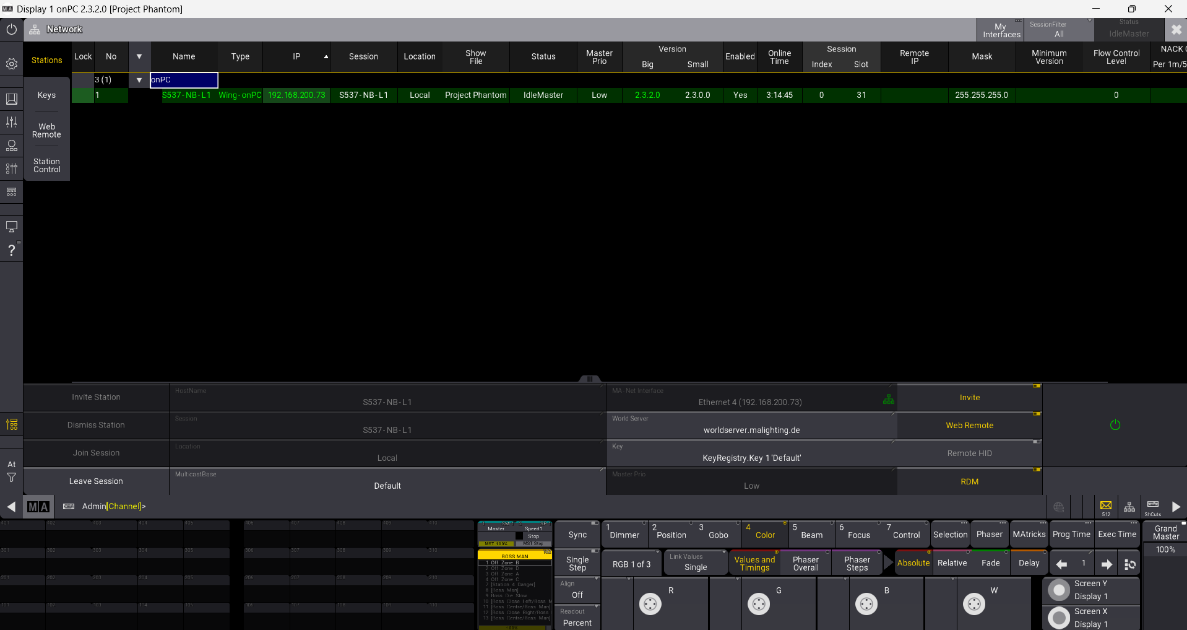
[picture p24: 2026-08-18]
Final/images/OSC LIGHT NETWORK SESSION.png

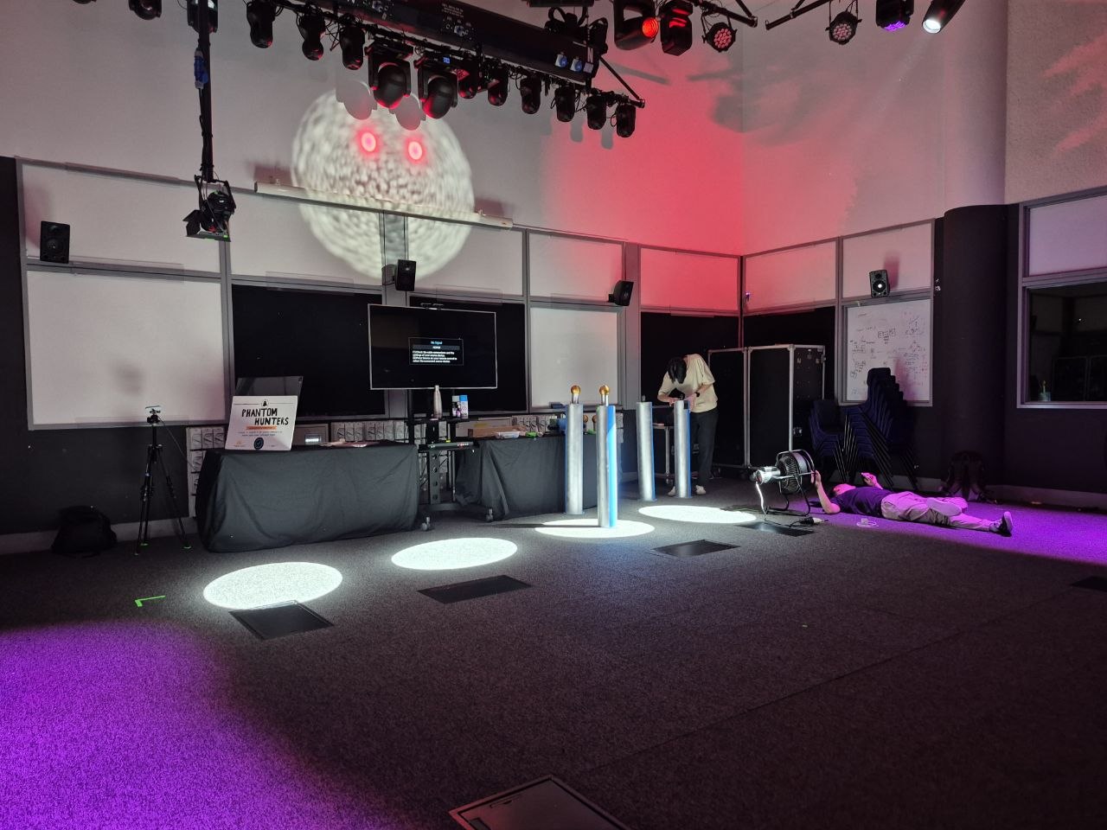
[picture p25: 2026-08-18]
Final/images/Q4.jpg

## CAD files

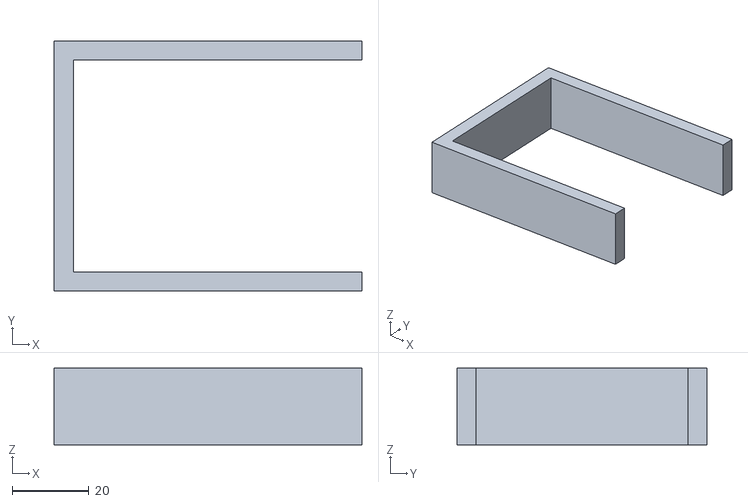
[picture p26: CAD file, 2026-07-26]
MVP/3dPrintedFiles/3D Print Gun/3D Print Isolate.stl
80.0 x 65.0 x 20.0

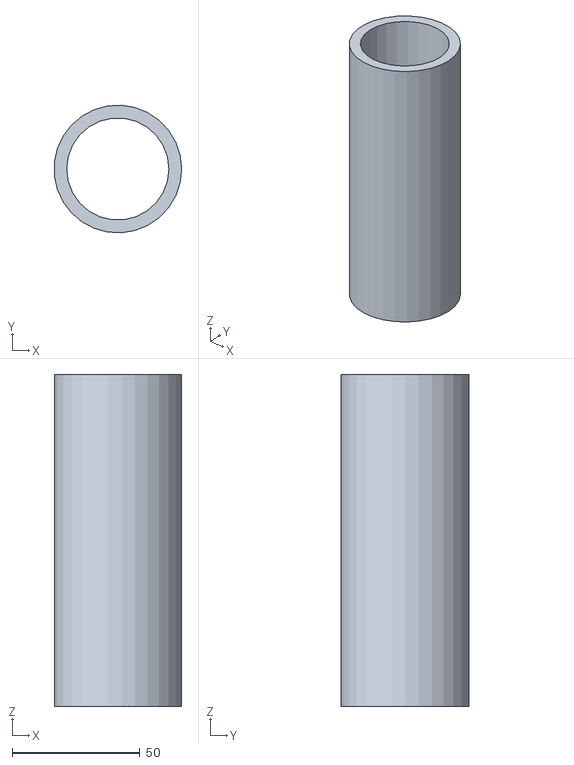
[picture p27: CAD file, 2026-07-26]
MVP/3dPrintedFiles/3D Print Gun/3D Print Cylinder.stl
49.9 x 49.9 x 130.0

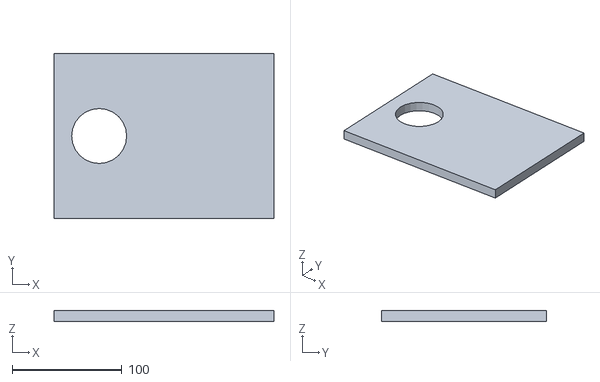
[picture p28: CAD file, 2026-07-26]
MVP/3dPrintedFiles/3D Print Gun/3D Print FINALBottom.stl
200.0 x 150.0 x 10.00

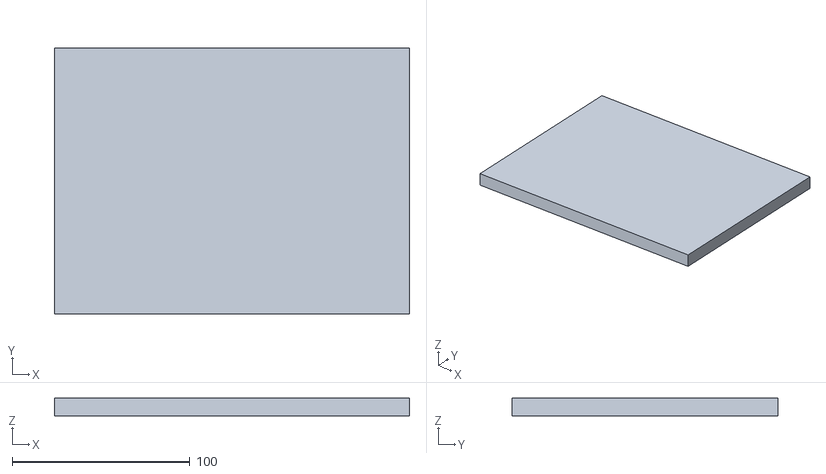
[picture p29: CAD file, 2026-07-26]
MVP/3dPrintedFiles/3D Print Gun/3D Print FINALTop.stl
200.0 x 150.0 x 10.00

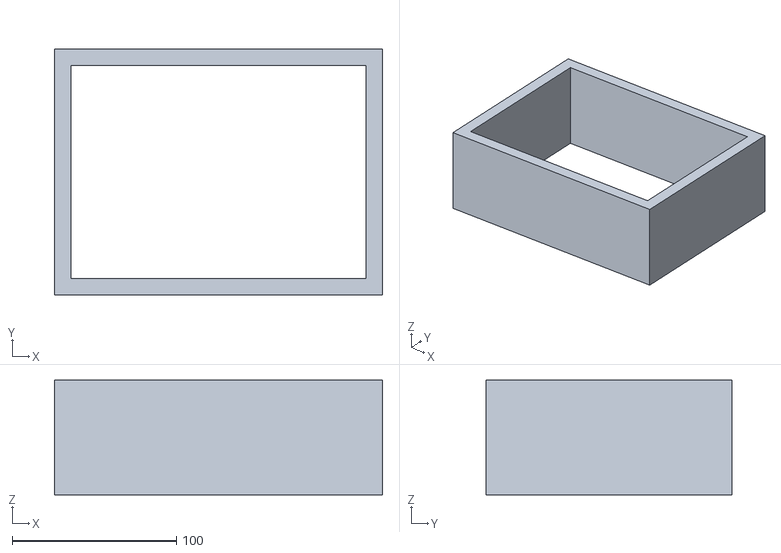
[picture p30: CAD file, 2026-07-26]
MVP/3dPrintedFiles/3D Print Gun/3D Print FINALBoxx.stl
200.0 x 150.0 x 70.0

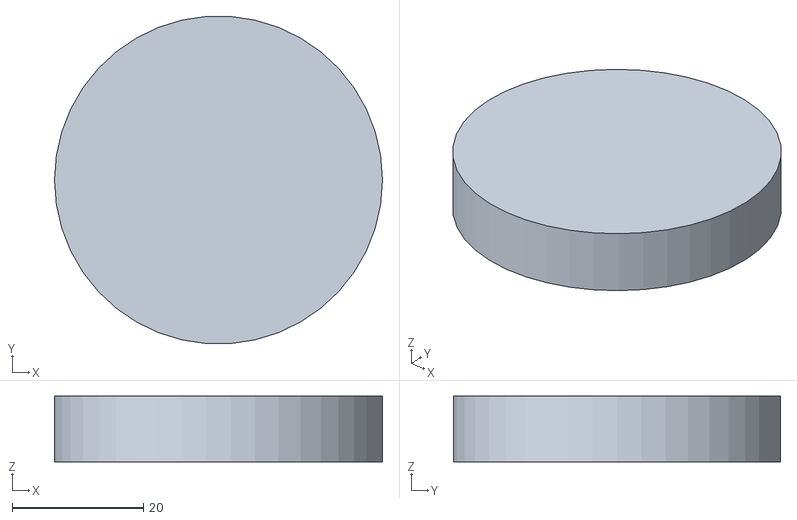
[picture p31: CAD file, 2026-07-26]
MVP/3dPrintedFiles/3D Print Gun/3D Print Cyclindercover.stl
50.0 x 49.9 x 10.00

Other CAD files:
MVP/3dPrintedFiles/holder.3mf
MVP/3dPrintedFiles/clamp.3mf
MVP/3dPrintedFiles/screws.3mf

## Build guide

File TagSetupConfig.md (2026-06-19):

# Tag Configuration

Back to [README.md](README.md)

## How it works
The system operates in Two-Way Ranging (TWR) mode, allowing the tag to measure its distance from each anchor (on the orange boxes) without requiring clock synchronization.   

For each measurement cycle, the moving tag exchanges three timestamped UWB messages with each anchor:
```mermaid
graph LR
A[Tag]--message-->B[Anchor]
```
```mermaid
graph RL
C[Anchor]--reply-->D[Tag]
```
```mermaid
graph LR
E[Tag]--final-->F[Anchor]
```
From the timestamps captured, the tag converts it into a distance, and doing so against the 6 anchors gives the tag a vector distance.  
  
The calculated distance measurements are then output through its data UART connection to a Receiving Raspberry Pi like so:

```mermaid
graph TD
A[BU03 Anchor 0]--UART-->B[Receiver rPi]
C[BU03 Anchor 1] --> A
D[BU03 Anchor 2] --> A
E[BU03 Anchor 3] --> A
F[BU03 Anchor 4] --> A
G[BU03 Anchor 5] --> A
B --OSC--> H[Game rPi]
H --OSC--> I[Multiplay ]
```
The Receiver rPi then sends the raw UART data to the Game rPi using uart.py, which then uses the known coordinates of the anchors to perform multilateration to determine the player's real-time position within the game environment.   
  
To improve tracking accuracy, calibration offsets are applied to compensate for ranging errors, and a Kalman filter is used to smooth position data and reduce measurement noise.   

## Configuration of BU03 modules
For this project, we need 6 boards configured as anchors A00 through A05, and 1 board configured as a tag.

To configure each board, this was the workflow: 

Step 1: Verify UART link (bu03_detect.py)  
Step 2: Configure each board (bu03_multi_config.py)  
Step 3: Inspect a board's saved config (bu03_inspect.py)  
Step 4: Calibrate per-anchor offsets (viewer_calibrate.py)  
Step 5: Run the game (GamePOC.py)  

After configuring the anchors

View the step by step guide [**here**](https://github.com/huats-club/stage_tracking#step-1--verify-uart-link-bu03_detectpy).  

### Anchors and Tag IDs
During configuration, ensure that each UWB module has a Anchor/Tag ID.  
If you find that the tracking on the viewer is not working as expected, for example tags are jittery and stick to each other, double-check that they have unique IDs.

---
Back to [README.md](README.md)

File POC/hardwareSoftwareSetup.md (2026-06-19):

# Hardware and Software Setup 
This file details how to set up and install the software dependencies and hardware needed to run the game. 

Back to [README.md](README.md) 

---
Following is the list of hardware we will be using.  

| Item | Qty | Remarks |
| --- | --- | --- |
| Raspberry Pi 4 Model B | 2 | 1 rPi for running game code, and another for receiving UWB data through UART.  |
| Multiplay | - | For synchronised audio feedback |
| Physical button | 1 | Connected to game rPi so it can take in the button input. |
| Jumper wires | 2 | Soldered to the button and connected to rPi GPIO 27 |

This guide will be focusing on:  
1. [Setting up your Raspberry Pi](#raspberry-pi-setup-first-inital-boot)
    * [Creating a Virtual Environment](#installing-virtual-environment)
    * [Connecting a button](#connecting-a-button)

2. [Multiplay](#multiplay)

## Raspberry Pi Setup: First inital boot
1. Update the Raspberry Pi.
```
sudo apt update
sudo apt upgrade
```
If this fails, set the date and time on the Raspberry Pi before trying again.
```
sudo date -s 'YYYY-MM-DD HH:MM:SS'
```
2. Enable SSH
To enable SSH, type:
```
sudo raspi-config
```
Select
``` '3 Interface Options' ``` and then ```P2 SSH```
Enable SSH.

3. Enable VNC (Virtual Network Computing)
Type:
```
sudo raspi-config
```
Select
``` '3 Interface Options' ``` and then ```P3 VNC```
Enable VNC.  
VNC allows remote controlling of another computer, in this case our rPi.

4. Enable HDMI Hotplug  

By enabling HDMI hotplug, VNC viewer will be able to work on our Raspberry Pi without a active HDMI connection.  

First type:
```
sudo nano /boot/config.txt
```

At the bottom of the file, paste
```
hdmi_force_hotplug=1
hdmi_group=2 # HDMI display group
hdmi_mode=82 # 1900 x 1080 resolution
```
```ctrl o``` to save, then ```ctrl x``` to escape.

5. Disable Screen Blanking  

Type:
```
sudo raspi-config
```
Select
``` '2 Display Options' ``` and then ```04 Screen Blanking```
Disable Screen Blanking.  
Your Raspberry Pi will no longer go to sleep from inactivity.

## Installing Virtual Environment

1. Install Python Virtualenv

```
sudo apt install virtualenv python3-virtualenv -y
```

2. Create a new virtual environment

```
python3 -m venv --system-site-packages <enviroment_name>
```
The virtual environment will created as a folder

3. Activate the virtual environment

```
source <environment_folder>/bin/activate
```

4. Install packages

```
pip3 install python-osc==1.8.1
pip install pyserial matplotlib
pip install RPi.GPIO==0.7.1
sudo apt-get install -y libopenblas-dev python3-pil.imagetk
```

5. To deactivate environment

```
deactivate
```

To run files in the environment, use Raspberry Pi's terminal and activate the virtual environment using
```
source <environment_folder>/bin/activate
```
Then, navigate to the folder with the file you want to run using the ```cd``` command.  
If you are unable to find it, use ```ls``` to view the files and folders inside your current working directory.

## Connecting a button
Below is a diagram of the Raspberry Pi's GPIO pinout.
![rPipinout](images/GPIO-Pinout-Diagram-2.png)
For our project, we will be using GPIO 27 (Pin 13) and connecting our button to it.

First, we will solder 2 female-female jumper wires to the button like so:
![btnimg](images/buttonWire.jpg)
This is to ensure that the wires will be secured to the button and will not fall out in the midst of gameplay.  

Next, simply connect one wire to a ground pin  in the Raspberry Pi, and the other to GPIO 27.
## Multiplay

Open Multiplay>Files>Preferences  
![multiplayPrefss](images/MultiplayPref.png)  
Then, open OSC Control and set the port to the corresponding port number while also enabling Control (Incoming).
![multiplayOSCss](images/multiplayOSC.png)

---
Back to [README.md](README.md)

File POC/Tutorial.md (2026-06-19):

# Game tutorial code
# Tutorial System Documentation

## Overview

The `tutorial.py` program serves as an interactive training module for the Ghost Hunting Game. It combines UWB positioning, real-time player tracking, audio guidance, button interaction, and a graphical user interface to teach players how to play the game before entering the main hunt.

The tutorial introduces players to the ghost hunting mechanics through a series of instructional screens and then transitions into a live practice session where players can locate and dispel ghosts using the same equipment and controls as the actual game. Unlike the main game, the tutorial does not include a countdown timer or win/lose conditions.

Back to [README.md](README.md)

---

## System Components

The tutorial system consists of the following major modules:

### 1. UWB Position Tracking

The system receives distance measurements from the BU03 UWB tracking system through OSC (Open Sound Control) messages.

The anchor locations are defined in the `ANCHORS` dictionary:

```python
ANCHORS = {
    0: (0.0, 0.0),
    1: (0.0, 0.50),
    2: (0.0, 1.0),
    3: (1.0, 1.0),
    4: (1.0, 0.50),
    5: (1.0, 0.0),
}
```

Each anchor has a fixed coordinate within the play area. Distance measurements from these anchors are used to determine the player's position.

---

### 2. Trilateration

The function `trilaterate_2d()` calculates the player's position using the measured distances from multiple anchors.

```python
def trilaterate_2d(anchor_positions, distances):
```

The algorithm:

1. Receives distance measurements from the anchors.
2. Uses least-squares multilateration.
3. Calculates the estimated X and Y coordinates of the player.

At least three valid anchors are required to calculate a position.

---

### 3. Kalman Filter

Raw UWB measurements may contain noise and fluctuations.

The `Kalman2D` class smooths the calculated position data.

```python
class Kalman2D:
```

The filter performs:

* Prediction of future position
* Correction using new measurements
* Velocity estimation
* Noise reduction

This produces smoother player movement on the tracking display.

---

## Ghost System

The tutorial contains two practice ghosts.

```python
Ghosts = [
    {
        "center": (0.25, 0.5),
        ...
    },
    {
        "center": (0.75, 1.0),
        ...
    }
]
```

Each ghost contains:

| Parameter  | Purpose |
| --- | --- |
| center | Ghost location |
| radius | Detection radius |
| min_radius | Minimum visual size |
| color | Display colour |
| label | Ghost name |
| active | Whether ghost is still present |

---

### Ghost Detection

The function:

```python
def ptInGhost(point, ghost):
```

checks whether the player is inside a ghost's containment field.

The player's position is compared with the ghost's centre point.

If the player is within:

```
ghost radius + hit tolerance
```

the function returns `True`.

---

## Audio Guidance System

To help players locate ghosts without relying solely on the screen, proximity-based sound cues are used.

### Sound Cue Thresholds

```python
SOUND_CUE_THRESHOLDS = [
    (0.0, "/cue/4/go"),
    (0.25, "/cue/3/go"),
    (0.625, "/cue/2/go"),
    (1.0, "/cue/1/go"),
]
```

The cue played depends on the distance between the player and the nearest active ghost.

| Distance | Cue |
| --- | ----- |
| On target | Cue 4 |
| Very close | Cue 3 |
| Medium range | Cue 2 |
| Far away | Cue 1 |

As the player approaches a ghost, the beeping frequency increases.

---

### Multiplay Integration

The `MultiplayClient` class sends OSC commands to Multiplay.

```python
class MultiplayClient:
```

Functions include:

#### stop_all()

Stops all currently playing audio cues.

```python
stop_all()
```

#### trigger()

Stops any existing cue and starts the requested cue.

```python
trigger(address)
```

This ensures only one proximity sound is active at any time.

---

## Button Input System

A physical button connected to Raspberry Pi GPIO 27 is used to dispel ghosts.

```python
BUTTON_PIN = 27
```

The GPIO library monitors button state changes.

```python
GPIO.add_event_detect(...)
```

When pressed:

1. The system checks the player's current position.
2. Determines whether the player is inside a ghost containment field.
3. If successful, the ghost is removed from the game.

---

## OSC Communication

The tutorial receives live tracking data using OSC.

### OSC Handler

```python
make_osc_handler(...)
```

The handler:

1. Receives distance measurements.
2. Performs trilateration.
3. Applies Kalman filtering.
4. Updates player position.
5. Updates ghost detection.
6. Controls proximity audio cues.

---

## User Interface

The graphical interface is built using:

* Tkinter
* Matplotlib

### Left Panel

Displays:

* Anchor locations
* Ghost locations
* Player position
* Tracking circles
* Position data table

### Right Panel

Displays tutorial instructions.

The tutorial consists of four steps:

1. Introduction
2. Understanding containment fields
3. Understanding detector beeps
4. Practice hunt

After completion, the tutorial panel is removed and the tracking display expands to full screen.

---

## Practice Hunt

After completing the instructional pages, the player enters a live practice hunt.

Features available:

* Real-time tracking
* Ghost detection
* Button interaction
* Audio guidance

Features disabled:

* Countdown timer
* Score tracking
* Win/Lose conditions

Players can freely practise locating and dispelling ghosts.

---

## Program Flow

1. Initialise GPIO button input.
2. Start OSC server.
3. Initialise Multiplay connection.
4. Launch graphical interface.
5. Receive UWB distance data.
6. Perform trilateration.
7. Apply Kalman filtering.
8. Update player position.
9. Generate proximity sound cues.
10. Detect ghost interactions.
11. Remove ghosts when successfully dispelled.
12. Shut down safely when the application closes.

This tutorial system provides players with a guided introduction to the Ghost Hunting Game while allowing them to practise the core mechanics using the actual hardware and tracking system before starting the main gameplay experience.

---
Back to [README.md](README.md)

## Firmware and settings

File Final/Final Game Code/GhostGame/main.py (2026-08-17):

#!/usr/bin/env python3
import argparse
import threading
import tkinter as tk

from pythonosc import dispatcher as osc_dispatcher
from pythonosc import osc_server

import game_logic
import lighting
from game_state import SharedState
from network import make_osc_handler
from display import ViewerApp

app = None

def repeat_current_question_intro():
    """Helper callback: Re-triggers current question intro audio and lighting cues after NO button finishes."""
    print(f"\n🔄 REPEATING INTRO for Question {game_logic.CURRENT_QUESTION}...")
    
    # Restart lighting sequence and cues
    lighting.start_question_lighting(game_logic.CURRENT_QUESTION)
    
    # Restart intro audio marker
    if app and hasattr(app, 'audio_controller'):
        if game_logic.CURRENT_QUESTION == 1:
            app.audio_controller.play_q1_intro()
        elif game_logic.CURRENT_QUESTION == 2:
            app.audio_controller.play_q2_intro()
        elif game_logic.CURRENT_QUESTION == 3:
            app.audio_controller.play_q3_intro()
        elif game_logic.CURRENT_QUESTION == 4:
            app.audio_controller.play_q4_intro()

def handle_tutorial_click():
    """Triggered when user clicks START TUTORIAL."""
    print("\n🎓 TUTORIAL STARTED: Turning ON Sequence 91...")
    lighting.start_tutorial_lighting()

def handle_start_click(state):
    """Triggered when user clicks START GAME."""
    with state.lock:
        state.game_active = True
        print("\n▶ GAME STARTED: Turning OFF Sequence 100 & 91, triggering Seq 93 & Track 6 Marker 20...")
        
        # Turn OFF startup sequence (100) and tutorial lighting (91)
        lighting.stop_startup_light()
        lighting.stop_tutorial_lighting()
        
        # Start Question 1 sequence (fires Seq 93 and schedules timed Cues 1-4)
        lighting.start_question_lighting(1)
        
        if app and hasattr(app, 'audio_controller'):
            app.audio_controller.play_q1_intro()

def handle_yes_click(state, root):
    """Triggered when user clicks YES."""
    with state.lock:
        if not state.game_won and state.game_active and not state.question_answered:
            hit_detected = False
            
            for tag_id, tag in enumerate(state.tags):
                if tag.filt_position is None:
                    continue
                
                for zi, ghost in enumerate(game_logic.Ghosts):
                    if ghost.get("active", True) and ghost.get("question") == game_logic.CURRENT_QUESTION:
                        if game_logic.ptInGhost(tag.filt_position, ghost):
                            print(f"\n✅ YES CONFIRMED: Tag {tag_id} in Question {game_logic.CURRENT_QUESTION} Zone!")
                            ghost["active"] = False
                            hit_detected = True

            if hit_detected:
                state.question_answered = True
                
                # Audio triggers for YES (Q1 - Q3 play Marker 22; Q4 handled in trigger_question_success_light)
                if app and hasattr(app, 'audio_controller'):
                    if game_logic.CURRENT_QUESTION < 4:
                        app.audio_controller.play_yes_q1_to_q3()
                
                # Turn OFF Question Sequence (93-96) & Run Success Sequence (86-89)
                audio_ctrl = app.audio_controller if (app and hasattr(app, 'audio_controller')) else None
                lighting.trigger_question_success_light(game_logic.CURRENT_QUESTION, audio_controller=audio_ctrl)

                if app:
                    if game_logic.CURRENT_QUESTION == 4:
                        state.game_won = True
                        root.after(0, app.show_end_game_state)
                    else:
                        root.after(0, app.show_continue_state)
            else:
                print(f"\n⚠️ ACTION DENIED: No tag inside Question {game_logic.CURRENT_QUESTION} Zone!")

def handle_no_click(state):
    """Triggered when user clicks NO."""
    print(f"\n❌ NO CLICKED: Playing Track 6 Marker 21 for 4s & Sequence 97 for 5s...")
    
    # Play Sequence 97 for 5 seconds on grandMA3
    lighting.trigger_no_button_sequence()
    
    # Play NO audio marker for 4s, then repeat the active question intro
    if app and hasattr(app, 'audio_controller'):
        app.audio_controller.play_no_button(on_finish_callback=repeat_current_question_intro)

def handle_continue_click(state, root):
    """Triggered when user clicks CONTINUE."""
    with state.lock:
        if state.question_answered and game_logic.CURRENT_QUESTION < 4:
            # Turn OFF current success sequence (86/87/88)
            lighting.handle_continue_lighting(game_logic.CURRENT_QUESTION)
            
            game_logic.CURRENT_QUESTION += 1
            state.question_answered = False
            print(f"\n➡️ CONTINUING: Moving to Question {game_logic.CURRENT_QUESTION}...")
            
            # Start Question Sequence for next Question (schedules Cues 1-4) & Play Audio
            lighting.start_question_lighting(game_logic.CURRENT_QUESTION)
            
            if app and hasattr(app, 'audio_controller'):
                if game_logic.CURRENT_QUESTION == 2:
                    app.audio_controller.play_q2_intro()
                elif game_logic.CURRENT_QUESTION == 3:
                    app.audio_controller.play_q3_intro()
                elif game_logic.CURRENT_QUESTION == 4:
                    app.audio_controller.play_q4_intro()
            
            if app: 
                root.after(0, app.reset_to_question_state)

def handle_end_game_click(state, root):
    """Triggered when user clicks END GAME."""
    print("\n🛑 END GAME: Stopping all audio, turning OFF Sequence 98, and exiting code...")
    
    # 1. Stop all REAPER audio immediately
    if app and hasattr(app, 'audio_controller'):
        app.audio_controller.stop_all_audio()

    # 2. Turn off lighting Sequence 98
    lighting.end_game_lighting_cleanup()
    
    if app:
        root.after(500, app.shutdown)

def main():
    global app
    ap = argparse.ArgumentParser()
    ap.add_argument("--tags", type=int, default=4)
    ap.add_argument("--port", type=int, default=game_logic.DEFAULT_PORT)
    ap.add_argument("--no-circles", action="store_true")
    ap.add_argument("--windowed", action="store_true")
    args = ap.parse_args()

    state = SharedState(n_tags=args.tags)
    state.game_active = False # Set game idle until START button is pressed
    
    for tag in state.tags:
        tag.kalman.dt = 0.10

    root = tk.Tk()

    anchor_ids = sorted(game_logic.ANCHORS.keys())
    anchor_positions_list = [game_logic.ANCHORS[i] for i in anchor_ids]
    
    disp = osc_dispatcher.Dispatcher()
    handler = make_osc_handler(state, anchor_ids, anchor_positions_list)
    disp.map("/distances", handler)

    server = osc_server.OSCUDPServer(("0.0.0.0", args.port), disp)
    threading.Thread(target=server.serve_forever, daemon=True).start()

    print(f"[game] Interactive Arena online via port {args.port}")
    
    app = ViewerApp(
        root, state, 
        show_circles=not args.no_circles, 
        fullscreen=not args.windowed,
        on_tutorial_callback=handle_tutorial_click,
        on_start_callback=lambda: handle_start_click(state),
        on_yes_callback=lambda: handle_yes_click(state, root),
        on_no_callback=lambda: handle_no_click(state),
        on_continue_callback=lambda: handle_continue_click(state, root),
        on_end_game_callback=lambda: handle_end_game_click(state, root)
    )

    # 1. Unmute all REAPER tracks on startup (No audio is triggered until START GAME is pressed)
    if hasattr(app, 'audio_controller'):
        app.audio_controller.unmute_all_tracks()

    # 2. Trigger Cue 2 on Sequence 100 on initial code launch
    lighting.trigger_initial_startup_light()

    try: 
        root.mainloop()
    except KeyboardInterrupt: 
        pass
    finally:
        state.stop = True
        server.shutdown()
        print("[game] System shut down safely.")

if __name__ == "__main__":
    main()

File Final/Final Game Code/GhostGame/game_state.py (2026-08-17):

# game_state.py
import time
import threading
from dataclasses import dataclass, field
from trilateration import Kalman2D

@dataclass
class TagState:
    last_distances: list = field(default_factory=lambda: [0.0] * 8)
    raw_position: tuple = None
    filt_position: tuple = None
    last_update: float = 0.0
    kalman: Kalman2D = field(default_factory=Kalman2D)
    ghosts_inside: set = field(default_factory=set)

class SharedState:
    def __init__(self, n_tags):
        self.n_tags = n_tags
        self.tags = [TagState() for _ in range(n_tags)]
        self.row_color_index = [-1] * n_tags
        self.lock = threading.Lock()
        
        # System tracking
        self.frame_count = 0
        self.start_time = time.time()
        self.stop = False
        
        # Game mechanics
        self.game_won = False
        self.game_active = True
        self.question_answered = False # Tracks if YES succeeded and waiting for CONTINUE

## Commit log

2026-06-17 added uart.py, content to readme, and sfx files.
2026-06-18 made adjustments to flow, renamed & moved files, added to readme.md
2026-07-26 Create 3D Print gun
